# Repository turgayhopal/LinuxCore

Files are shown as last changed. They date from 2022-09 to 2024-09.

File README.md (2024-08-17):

# Linux-Core Development Board

- This project goal is developing myself about embedded linux environment like buildroot, the yacto project.

### Linux Core v2 Features

- NUC980 Series Microprocessor
- 2A Step-Down Voltage Regulator 1.2V, 1.8V, 3.3V
- RLT8188EU WIFI USB Module
- CP2102 USB TTL
- ILI9143 TFT LCD Header
- NAU88C22YG Audio Speaker
- Cam Slot
- SPI Nand External Flash
- MDBT5DQ (NRF52840 Bluetooth Bodule with USB) (Experimental !!!)
- 2 USB Host Socket
- 2 - 2x10 User Pin Header
- SD Card Slot
- 4 User LED's

### PCB Features

- 60.1mm x 80.1mm
- 1mm board thickness.
- 4 layer PCB.
- 0.45 / 0.3 vias

### Linux Core v1 Features

- NUC980 Series Microprocessor
- 2A Step-Down Voltage Regulator 1.2V, 1.8V, 3.3V
- RLT8188EU WIFI USB Module
- CP2102 USB TTL
- 128 KB External SPI-NOR Flash
- SD Card Slot
- 3 User LED's

### PCB Features

- 52.6mm x 57.5mm
- 1.6mm board thickness.
- 2 layer PCB.
- 0.6 / 0.3 vias

## Linux Core v2 Images

### Right Side
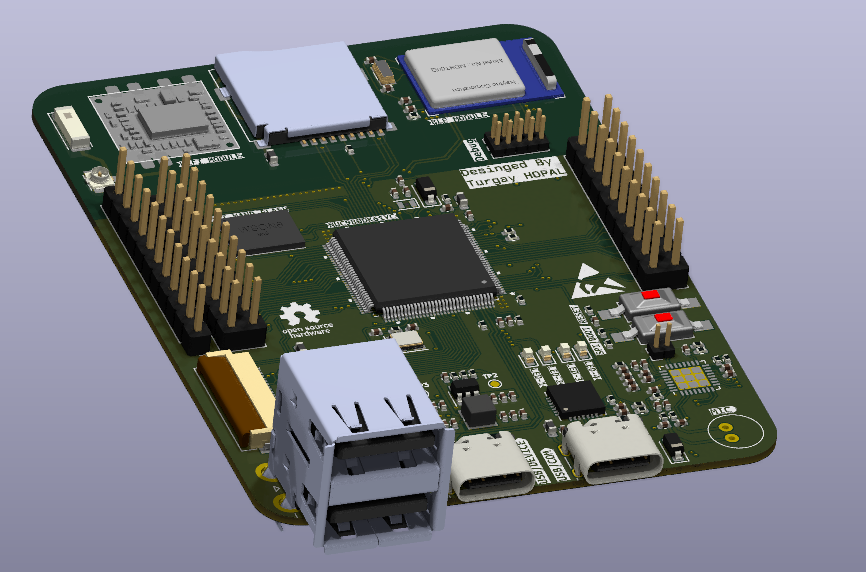
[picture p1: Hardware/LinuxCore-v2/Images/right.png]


### Front Side
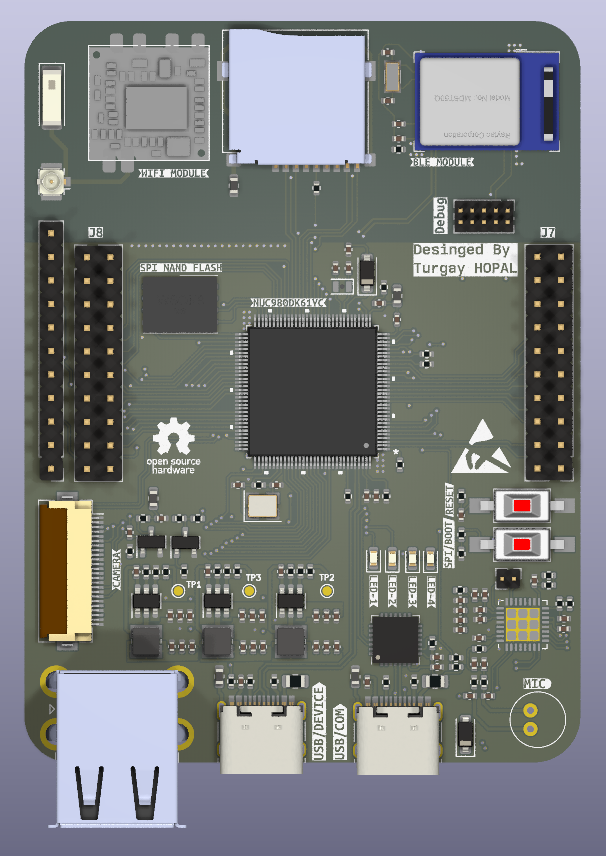
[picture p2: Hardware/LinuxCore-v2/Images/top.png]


### Back Side
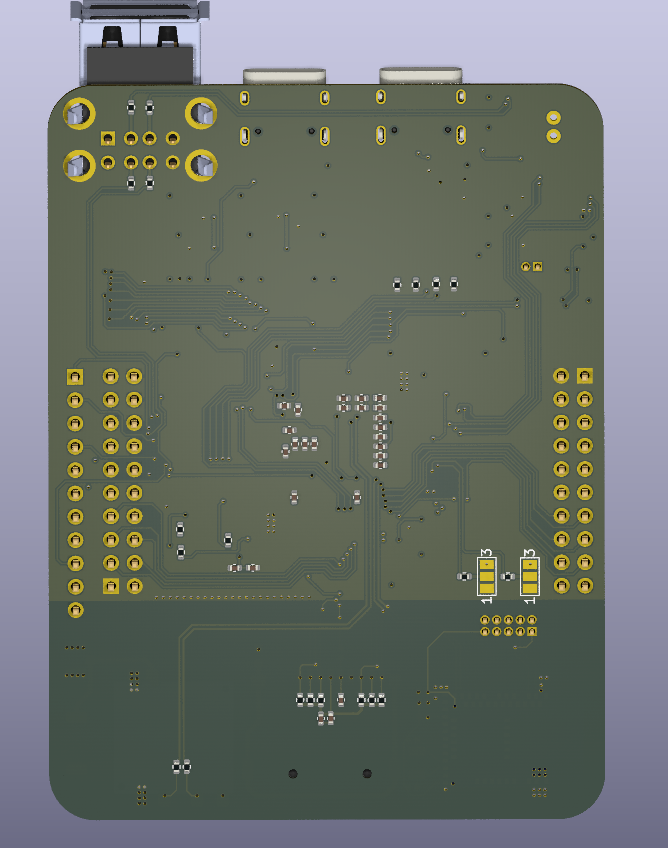
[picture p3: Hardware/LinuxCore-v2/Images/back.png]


### LCD
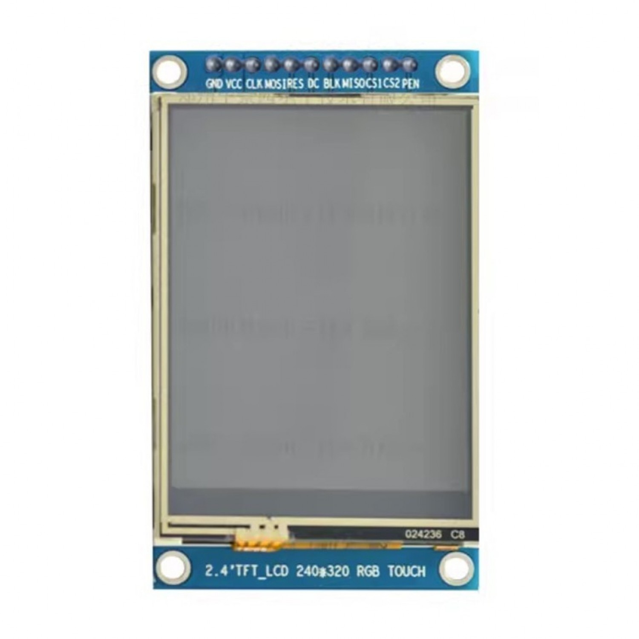
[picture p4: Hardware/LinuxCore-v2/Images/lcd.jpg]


## Linux Core v1 Images

### Right Side
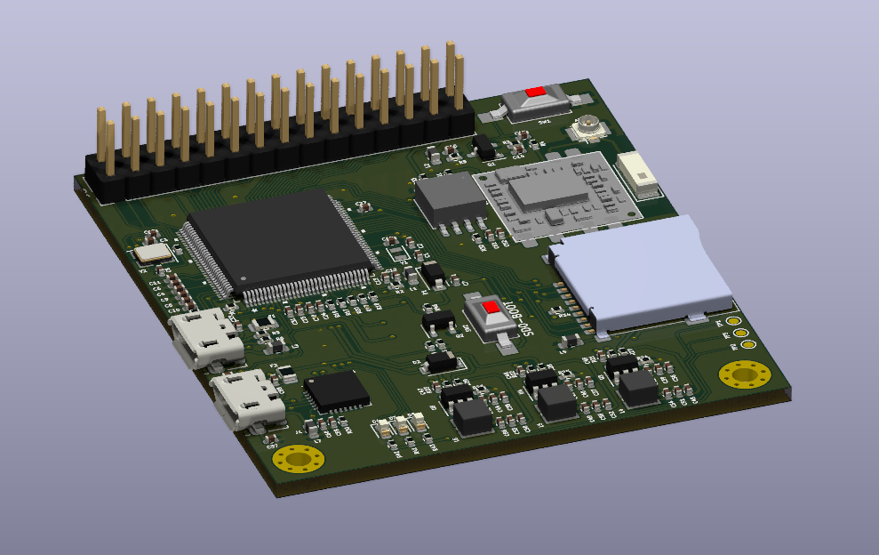
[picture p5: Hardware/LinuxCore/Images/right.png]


### Front Side
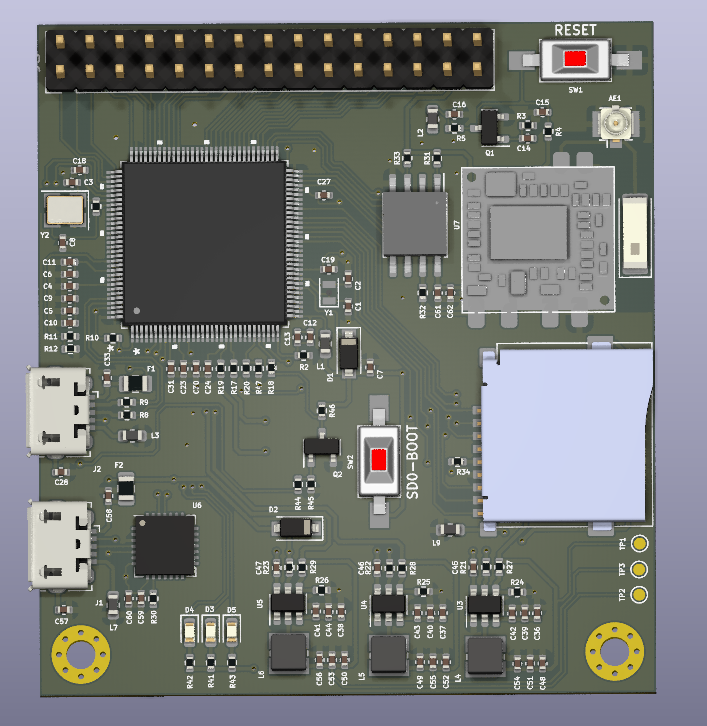
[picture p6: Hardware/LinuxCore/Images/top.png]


### Back Side
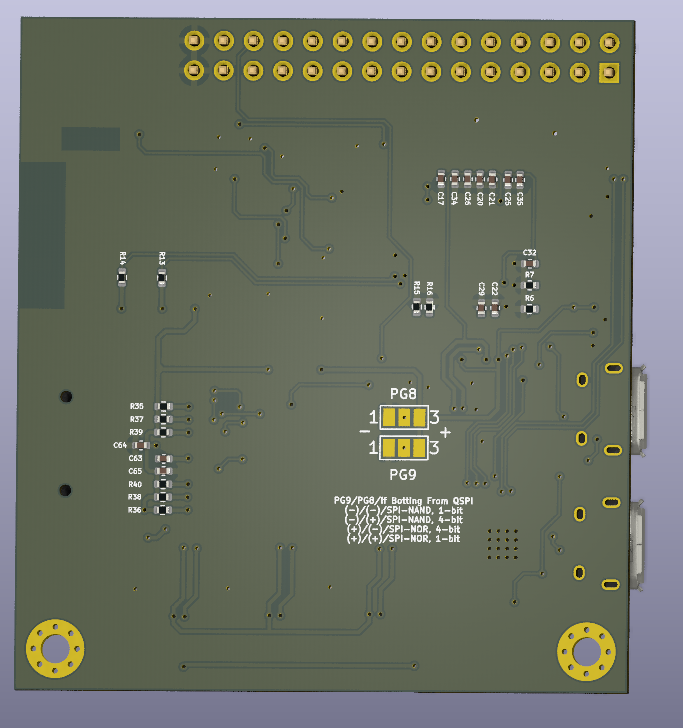
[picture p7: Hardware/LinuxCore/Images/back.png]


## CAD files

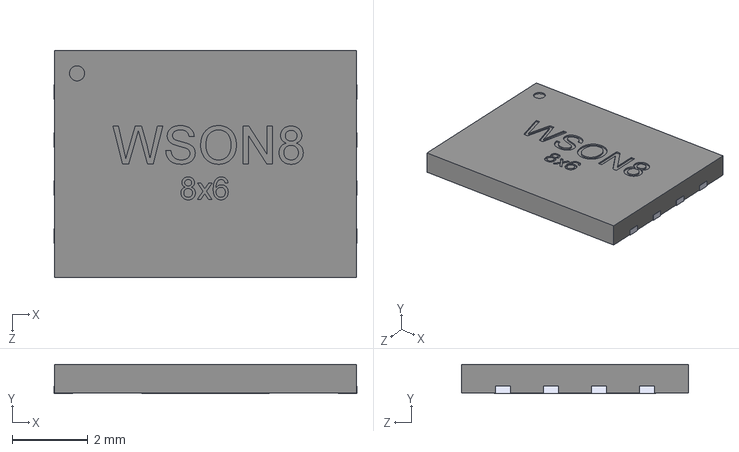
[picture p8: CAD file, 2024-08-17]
Hardware/LinuxCore-v2/3DModels/WSON8-8x6.STEP
8.02 x 0.77 x 6.00 mm

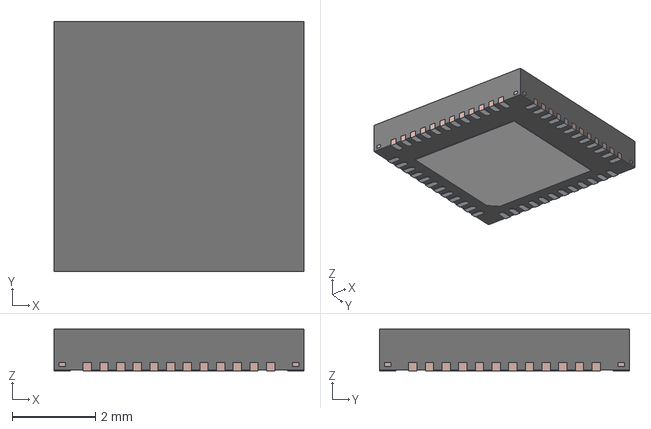
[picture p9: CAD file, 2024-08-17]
Hardware/LinuxCore-v2/3DModels/RSL0048A.stp
6.00 x 6.00 x 1.00 mm
FRAME

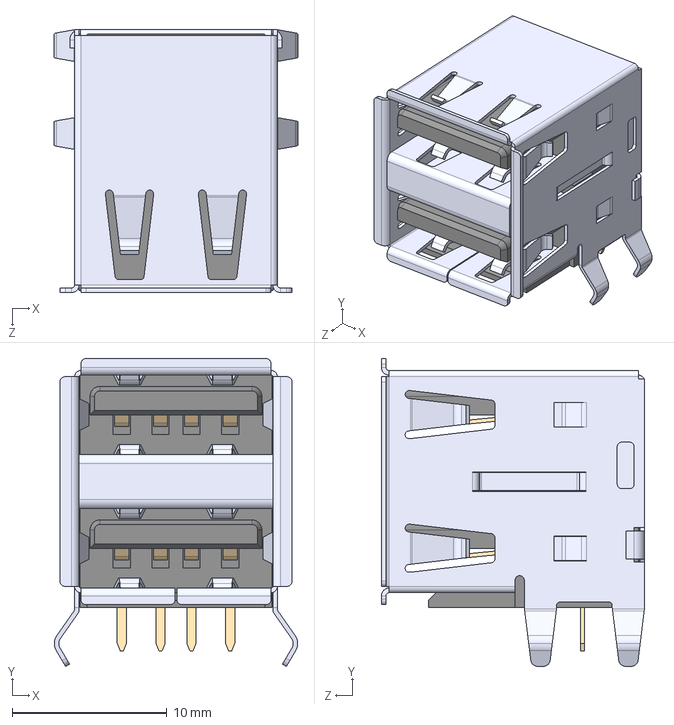
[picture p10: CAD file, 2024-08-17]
Hardware/LinuxCore-v2/3DModels/USB1035-GF-P-0-B-B.STEP
15.7 x 19.9 x 17.0 mm

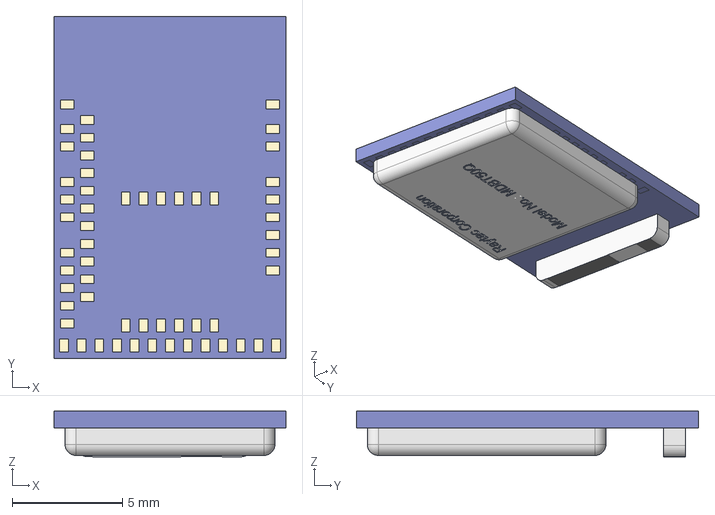
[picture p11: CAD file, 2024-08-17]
Hardware/LinuxCore-v2/3DModels/MDBT50Q-1MV2.STEP
10.5 x 15.5 x 2.06 mm

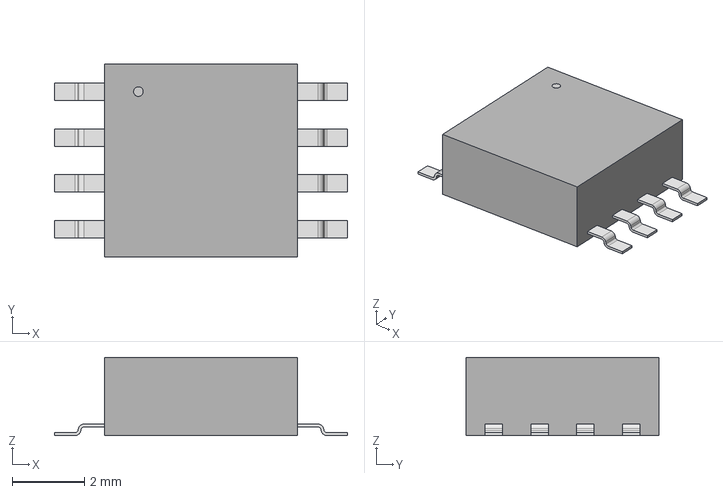
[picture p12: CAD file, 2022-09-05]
Hardware/LinuxCore-v2/3DModels/SOIC_128JVSIM_WIN.step
8.10 x 5.33 x 2.16 mm

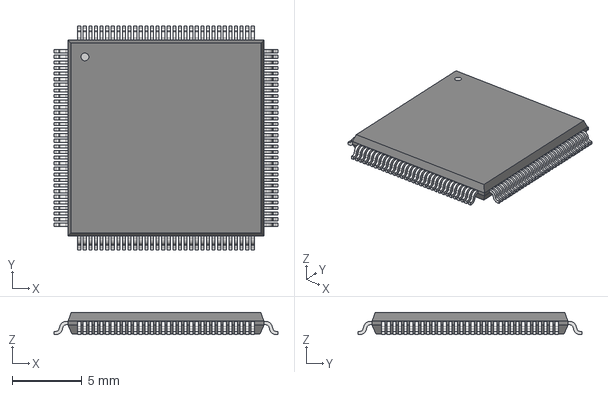
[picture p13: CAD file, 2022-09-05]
Hardware/LinuxCore-v2/3DModels/LQFP128_14X14X1_4_NUV.step
16.0 x 16.0 x 1.60 mm

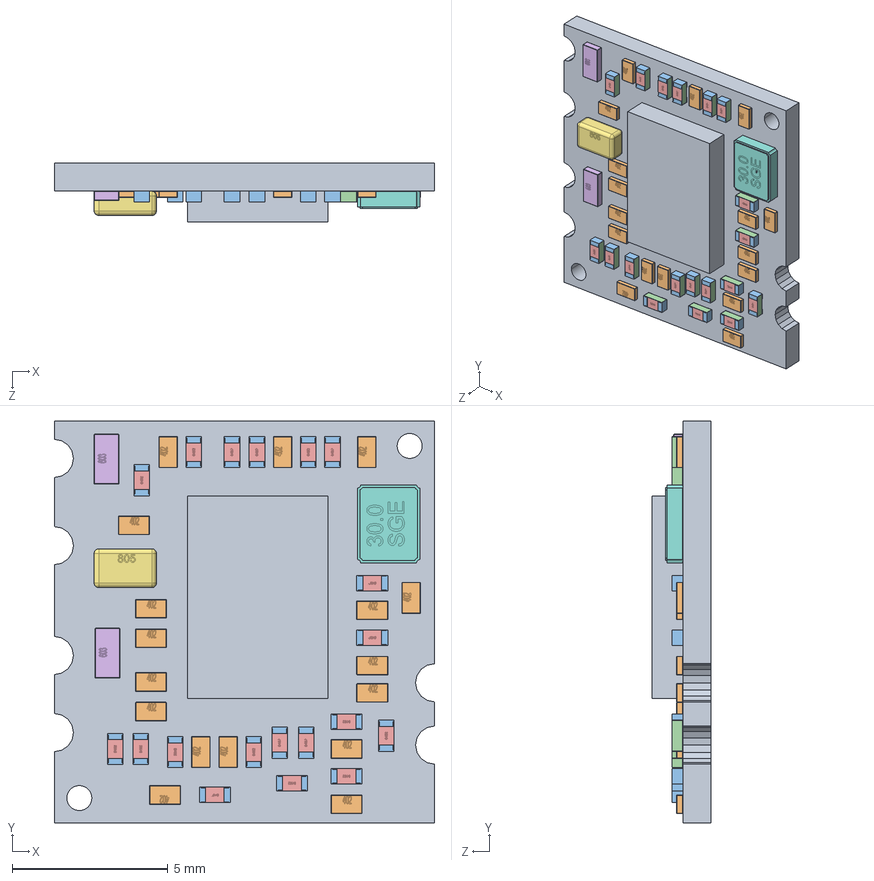
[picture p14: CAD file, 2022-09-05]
Hardware/LinuxCore-v2/3DModels/User Library-JCX12.STEP
12.2 x 12.9 x 1.89 mm
Board
CAP0402 x 17
RES0402 x 19
CAP0603 x 2
CAP0805
SX-2520
Extruded

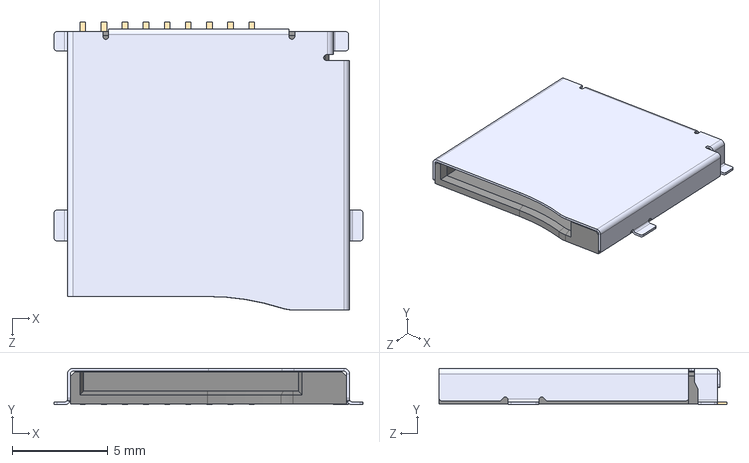
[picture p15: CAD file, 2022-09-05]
Hardware/LinuxCore-v2/3DModels/GTFP08131Y2HR.step
16.1 x 1.90 x 15.0 mm

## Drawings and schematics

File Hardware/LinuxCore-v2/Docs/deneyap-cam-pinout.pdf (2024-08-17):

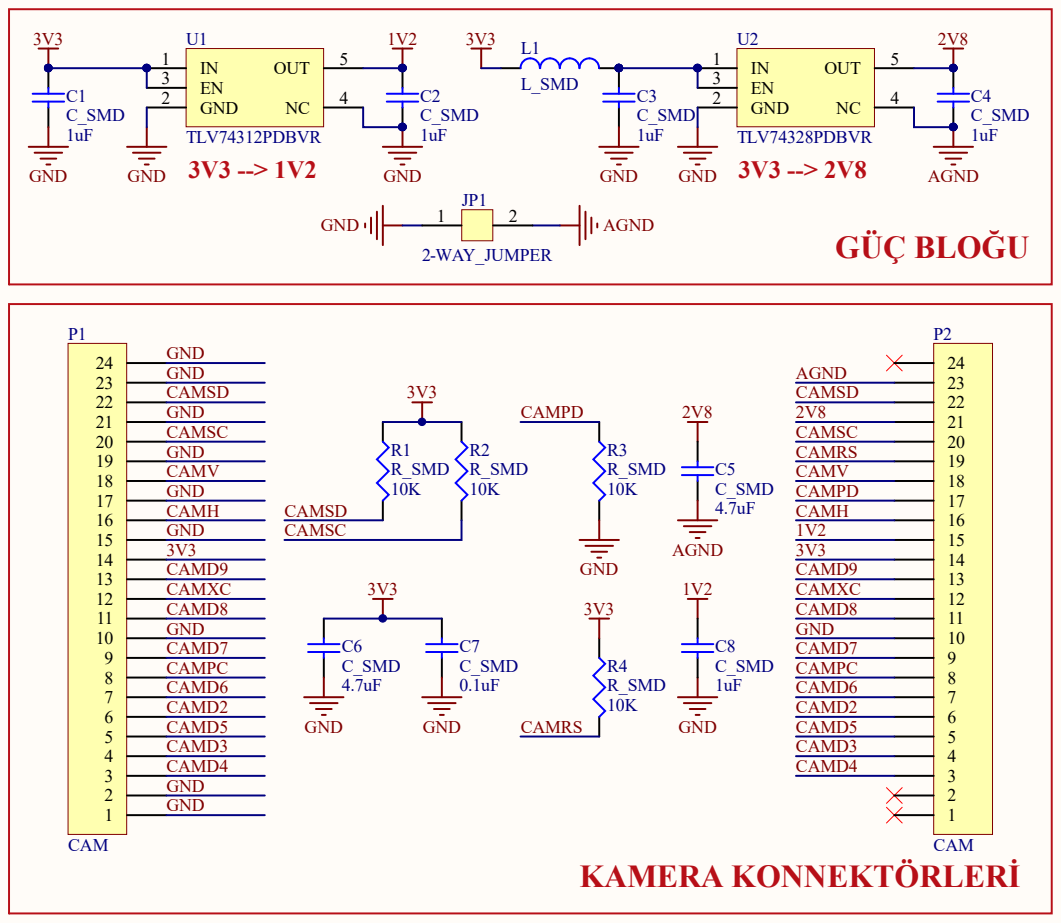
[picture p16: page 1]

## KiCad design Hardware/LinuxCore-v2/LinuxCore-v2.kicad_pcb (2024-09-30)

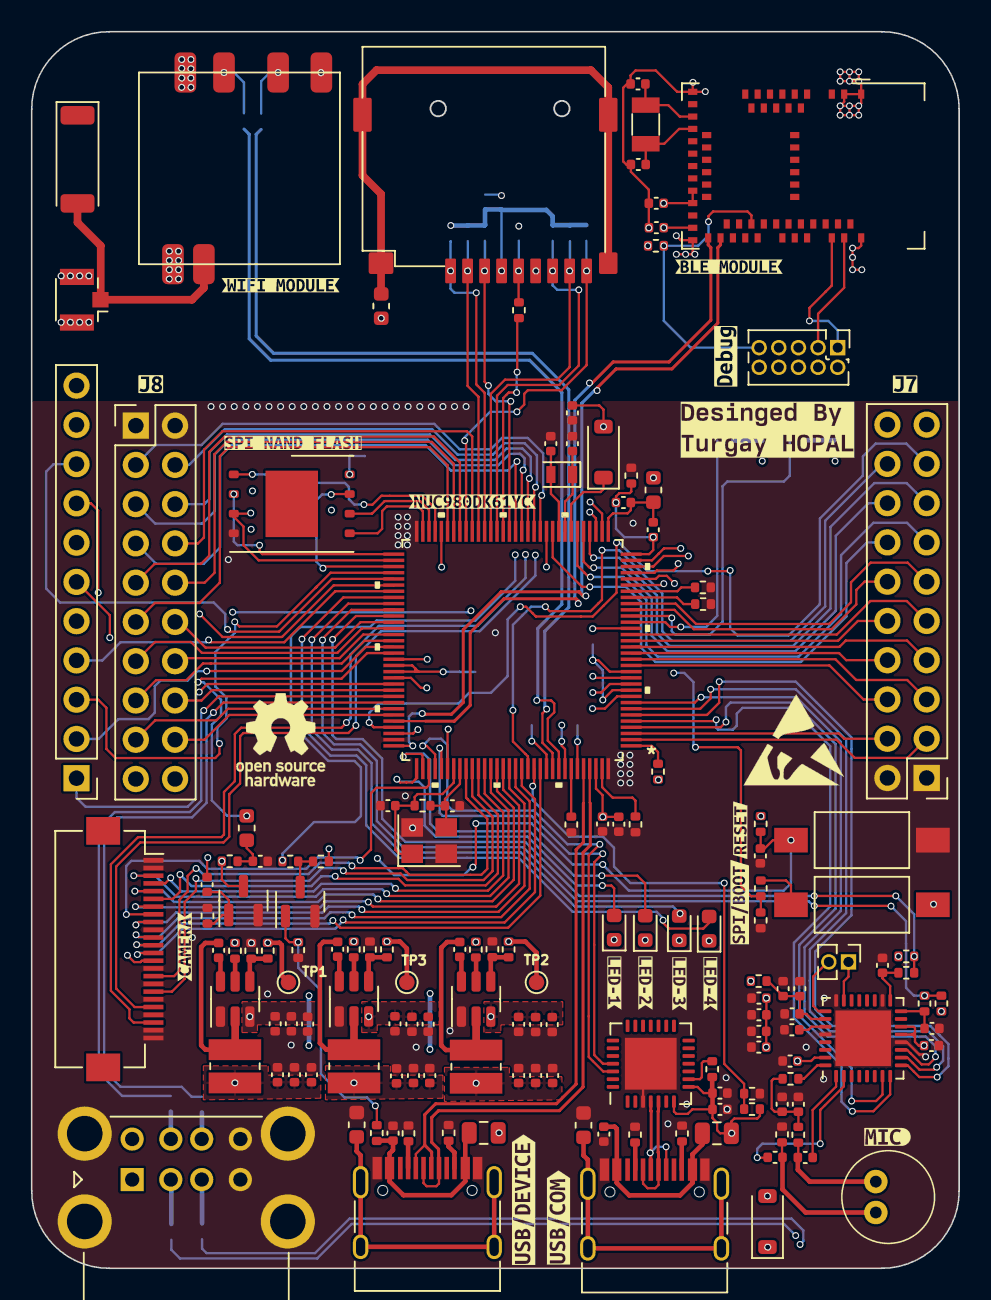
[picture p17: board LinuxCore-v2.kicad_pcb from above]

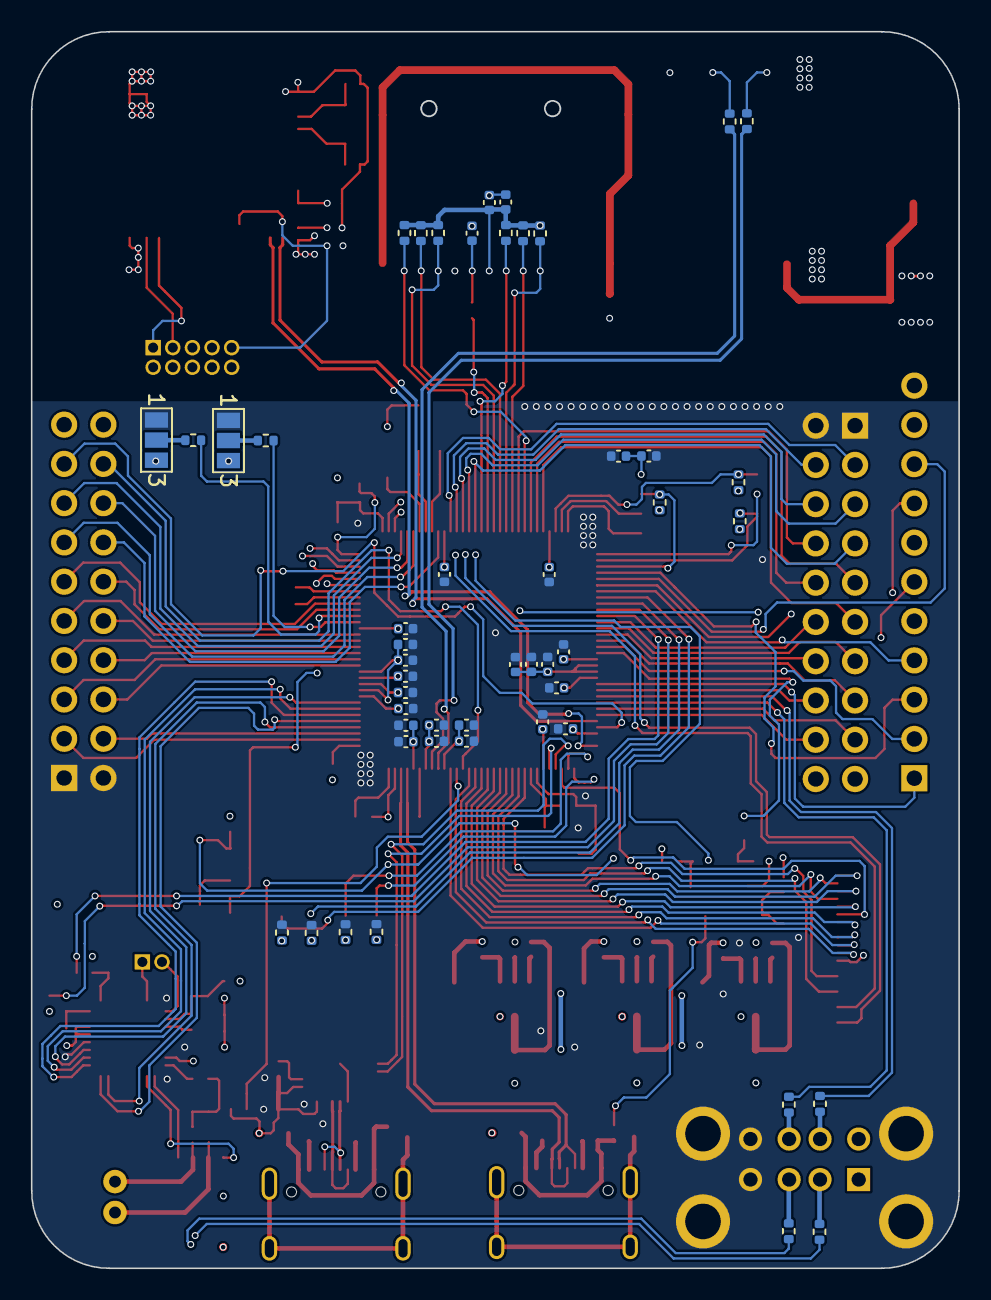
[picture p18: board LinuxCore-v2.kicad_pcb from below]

Board: 4 copper layers, 60.0 x 80.0 mm, 214 parts (49 on the bottom side), 174 nets.

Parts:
AE1: Antenna_Shield; U.FL_Hirose_U.FL-R-SMT-1_Vertical
AE2: Antenna_Shield; Johanson_2450AT43F0100
C1, C2, C3, C8: 15pF; C_0402_1005Metric
C4, C5, C6, C12, C33, C34, C38, C39, C40, C41, C42, C43, C61, C65, C66, C67, C69, C72, C78: 10uF; C_0402_1005Metric
C7, C9, C10, C11, C13, C17, C18, C19, C20, C21, C22, C23, C24, C25, C26, C27, C29, C30, C31, C32, C36, C37, C44, C45, C46, C47, C48, C49, C50, C51, C52, C60: 0.1uF; C_0402_1005Metric
C14, C15, C16, C28, C35, C53, C54, C55, C56, C57, C58, C70, C71: 1uF; C_0402_1005Metric
C59: NC; C_0402_1005Metric
C62, C63, C64, C68, C73, C74, C75, C77, C79: 100nF; C_0402_1005Metric
C76, C82, C83: 4.7uF; C_0402_1005Metric
C80, C81: 12pF; C_0402_1005Metric
D1: 30V 200mA; D_SOD-123
D2: B240; D_SOD-123
D3, D4, D5, D6: LED; LED_0603_1608Metric
F1, F2: 6V/1.5A; Fuse_0805_2012Metric
J1, J2: USB_C_Receptacle_USB2.0; USB_C_Receptacle_HRO_TYPE-C-31-M-12
J3: Conn_01x11_Pin; PinHeader_1x11_P2.54mm_Vertical
J4: Conn_01x24; Hirose_FH12-24S-0.5SH_1x24-1MP_P0.50mm_Horizontal
J5: NRF_Debug; PinHeader_2x05_P1.27mm_Vertical
J6: USB_A_Stacked; USB_A_CUI_UJ2-ADH-TH_Horizontal_Stacked
J7, J8: Conn_02x10_Odd_Even; PinHeader_2x10_P2.54mm_Vertical
JP1, JP2: SolderJumper_3_Open; SolderJumper-3_P1.3mm_Open_Pad1.0x1.5mm_NumberLabels
L1, L2, L3, L4, L8: 220R; L_0603_1608Metric
L5, L6, L7: 2.2uH; L_Wuerth_MAPI-3020
LS1: Speaker; PinHeader_1x02_P1.27mm_Vertical
Q1, Q2: MMBT3904; SOT-23
R1: 1M; R_0402_1005Metric
R2, R37, R48: 0R; R_0402_1005Metric
R3, R4, R12: 100K; R_0402_1005Metric
R5: 470R; R_0402_1005Metric
R6, R21, R23, R60, R61, R62, R63: 1K; R_0402_1005Metric
R7, R8, R25, R26, R56, R57, R58, R59: 5.1K; R_0402_1005Metric
R9: 20K; R_0402_1005Metric
R10: 39K; R_0402_1005Metric
R11, R13: 12.1K; R_0402_1005Metric
R14, R15: 4.7R; R_0402_1005Metric
R16, R17, R18, R19, R20, R22, R24, R27, R28, R29, R30, R31, R32, R33, R38, R39, R40, R41, R42, R43, R52, R53, R54, R55: 10K; R_0402_1005Metric
R34: 33.2K; R_0402_1005Metric
R35: 5.76K; R_0402_1005Metric
R36: 13.7K; R_0402_1005Metric
R44, R45, R46, R47: 33R; R_0402_1005Metric
R49, R50: 2.2K; R_0402_1005Metric
R51: 680R; R_0402_1005Metric
SW1, SW2: SW_Push; SW_SPST_FSMSM
TP1, TP2, TP3: TestPoint; TestPoint_Pad_D1.0mm
U1: NUC980DK61YC
U2: RLT8188_WIFI_MODUL
U3: CP2102N-Axx-xQFN28; QFN-28-1EP_5x5mm_P0.5mm_EP3.35x3.35mm
U4, U5, U6: TPS562200; SOT-23-6
U7: L-KLS1-TF-003; L-KLS1-TF-003-H1.85-R
U8: NAU88C22; QFN-32-1EP_5x5mm_P0.5mm_EP3.6x3.6mm
U9: F35SQA001G
U10: MDBT50Q-P1MV2; Raytac_MDBT50Q
U11: L-KLS3-MM6027PP-443
Y1: Crystal; Crystal_SMD_2012-2Pin_2.0x1.2mm
Y2: Crystal_GND24; Crystal_SMD_3225-4Pin_3.2x2.5mm
Y3: 32.768kHz; Crystal_SMD_3215-2Pin_3.2x1.5mm
kibuzzard-665B7D91: G***; kibuzzard-665B7D91
kibuzzard-665B7DAC: G***; kibuzzard-665B7DAC
kibuzzard-665B7DDA: G***; kibuzzard-665B7DDA
kibuzzard-665B7E6F: G***; kibuzzard-665B7E6F
kibuzzard-665B7E8B: G***; kibuzzard-665B7E8B
kibuzzard-665B7E24: G***; kibuzzard-665B7E24
kibuzzard-665B7E38: G***; kibuzzard-665B7E38
kibuzzard-665B7E84: G***; kibuzzard-665B7E84
kibuzzard-665B7E87: G***; kibuzzard-665B7E87
kibuzzard-665B7EA2: G***; kibuzzard-665B7EA2
kibuzzard-665B7EF0: G***; kibuzzard-665B7EF0
kibuzzard-665B7F01: G***; kibuzzard-665B7F01
kibuzzard-665B7F18: G***; kibuzzard-665B7F18
kibuzzard-665B7F32: G***; kibuzzard-665B7F32
kibuzzard-665B7FB9: G***; kibuzzard-665B7FB9
kibuzzard-665B7FBD: G***; kibuzzard-665B7FBD
kibuzzard-665C90BB: G***; kibuzzard-665C90BB
kibuzzard-665C92C9: G***; kibuzzard-665C92C9

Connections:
+1V2: C6.2, C11.2, C14.1, C17.2, C19.2, C22.2, C25.2, C29.2, C32.2, C34.2, C52.2, C55.2, C58.2, L7.2, R35.2, TP2.1, U1.10 (VDD), U1.13 (VDD), U1.43 (VDD), U1.82 (VDD), U1.94 (VDD), U1.118 (VDD), U1.123 (USB0_VDD)
+1V8: C20.1, C23.1, C26.1, C30.1, C33.1, C51.2, C54.2, C57.2, L6.2, R36.2, TP3.1, U1.11 (MVDD), U1.12 (MVDD), U1.83 (MVDD), U1.84 (MVDD)
+3V3: C4.2, C5.2, C7.2, C9.2, C10.2, C18.1, C21.1, C24.1, C27.1, C31.1, C50.2, C53.2, C56.2, C60.1, C61.1, C62.1, C63.1, C64.1, C66.1, C74.1, C75.2, C78.2, C79.2, C83.2, D1.2 (A), J3.5, J3.7, J3.10, J4.14, J5.2, J7.19, J7.20, J8.19, J8.20, JP1.3 (B), JP2.3 (B), L1.1, L5.2, R4.1, R12.1, R19.1, R34.2, R38.2, R39.2, R40.2, R41.2, R42.2, R43.2, R44.2, R45.2, R48.1, R52.1, R53.2, R54.1, R55.2, SW2.1, TP1.1, U1.9 (VDDIO), U1.20 (VDDIO), U1.60 (VDDIO), U1.85 (VDDIO), U1.102 (VDDIO), U1.121 (USB1_VDD33), U1.126 (USB0_VDD33), U2.1 (3V3), U7.4 (VDD), U8.13 (VDDC), U8.14 (VDDB), U8.31 (VDDA), U9.8 (VCC), U10.28 (VDD), U10.30 (VDDH)
/AUDIO/I2S_BCLK: U1.5 (PA-3), U8.8 (BCLK)
/AUDIO/I2S_DI: U1.6 (PA-4), U8.9 (ADCOUT)
/AUDIO/I2S_DO: U1.7 (PA-5), U8.10 (DACIN)
/AUDIO/I2S_LRCK: U1.4 (PA-2), U8.7 (FS)
/AUDIO/I2S_MCLK: U1.8 (PA-6), U8.11 (MCLK)
/AUDIO/LMICN: C71.2, U8.2 (LMICN)
/AUDIO/LMICP: C70.2, U8.1 (LMICP)
/AUDIO/LSPKOUT: LS1.2, U8.25 (LSPKOUT)
/AUDIO/RSPKOUT: LS1.1, U8.23 (RSPKOUT)
/AUDIO/SCL: R45.1, R47.1, U1.74 (PD-14)
/AUDIO/SCL_: C67.1, R47.2, U8.16 (SCLK)
/AUDIO/SDA: R44.1, R46.1, U1.75 (PD-15)
/AUDIO/SDA_: C65.1, R46.2, U8.17 (SDIO)
/AUDIO/SPK_3V3: C68.1, C69.1, C77.2, R48.2, U8.26 (VDDSPK)
/AUDIO/VREF: C76.2, U8.27 (VREF)
/BLE Module/NRESET: J5.9, R55.1, U10.40 (~RESET/P0.18)
/BLE Module/SWDCLK: J5.3, U10.53 (SWDCLK)
/BLE Module/SWDIO: J5.1, U10.51 (SWDIO)
/BLE Module/USB_D+: U1.96 (PF-7), U10.35 (D+)
/BLE Module/USB_D-: U1.92 (PF-6), U10.34 (D-)
/BLE Module/XL1: C80.1, U10.17 (XL1/P0.00), Y3.1
/BLE Module/XL2: C81.1, U10.18 (XL2/P0.01), Y3.2
/Deneyap Kamera/CAMD2: J4.6, U1.107 (PE-2)
/Deneyap Kamera/CAMD3: J4.4, U1.108 (PE-3)
/Deneyap Kamera/CAMD4: J4.3, U1.109 (PE-4)
/Deneyap Kamera/CAMD5: J4.5, U1.110 (PE-5)
/Deneyap Kamera/CAMD6: J4.7, U1.111 (PE-6)
/Deneyap Kamera/CAMD7: J4.9, U1.112 (PE-7)
/Deneyap Kamera/CAMD8: J4.11, U1.113 (PE-8)
/Deneyap Kamera/CAMD9: J4.13, U1.114 (PE-9)
/Deneyap Kamera/CAMH: J4.16, U1.105 (PE-0)
/Deneyap Kamera/CAMPC: J4.8, U1.99 (PF-10)
/Deneyap Kamera/CAMSC: J4.20, U1.35 (PB-5)
/Deneyap Kamera/CAMSD: J4.22, U1.34 (PB-7)
/Deneyap Kamera/CAMV: J4.18, U1.106 (PE-1)
/Deneyap Kamera/CAMXC: J4.12, U1.117 (PE-12)
/Header1/3: J7.3, U1.2 (PA-0)
/Header1/4: J7.4, U1.3 (PA-1)
/Header1/5: J7.5, U1.15 (PA-8)
/Header1/6: J7.6, U1.14 (PA-7)
/Header1/7: J7.7, U1.17 (PA-10)
/Header1/8: J7.8, U1.16 (PA-9)
/Header1/9: J7.9, U1.19 (PA-12)
/Header1/10: J7.10, U1.18 (PA-11)
/Header1/11: J7.11, U1.24 (PG-6)
/Header1/12: J7.12, U1.23 (PG-7)
/Header1/13: J7.13, U1.38 (PB-2)
/Header1/14: J7.14, U1.42 (PB-8)
/Header1/15: J7.15, U1.36 (PB-1)
/Header1/16: J7.16, U1.37 (PB-3)
/Header1/17: J7.17, U1.93 (PB-13)
/Header1/18: J7.18, U1.115 (PE-10)
/Header2/3: J8.3, U1.44 (PC-0)
/Header2/4: J8.4, U1.45 (PC-1)
/Header2/5: J8.5, U1.47 (PC-3)
/Header2/6: J8.6, U1.46 (PC-2)
/Header2/7: J8.7, U1.48 (PC-4)
/Header2/8: J8.8, U1.55 (PC-11)
/Header2/9: J8.9, U1.57 (PC-13)
/Header2/10: J8.10, U1.58 (PC-14)
/Header2/11: J8.11, U1.59 (PC-15)
/Header2/12: J8.12, U1.76 (PG-11)
/Header2/13: J8.13, U1.77 (PG-12)
/Header2/14: J8.14, U1.78 (PG-13)
/Header2/15: J8.15, U1.79 (PG-14)
/Header2/16: J8.16, U1.87 (PF-1)
/Header2/17: J8.17, U1.90 (PF-4)
/Header2/18: J8.18, U1.91 (PF-5)
/ILI9143 TFT LCD/CLK: J3.9, U1.69 (PD-9)
/ILI9143 TFT LCD/CS1: J3.3, U1.68 (PD-8)
/ILI9143 TFT LCD/CS2: J3.2, U1.80 (PG-15)
/ILI9143 TFT LCD/DC: J3.6, U1.29 (PB-0)
/ILI9143 TFT LCD/MISO: J3.4, U1.71 (PD-11)
/ILI9143 TFT LCD/MOSI: J3.8, U1.70 (PD-10)
/ILI9143 TFT LCD/PEN: J3.1, U1.86 (PF-0)
/MPU/PB4: R56.2, U1.31 (PB-4)
/MPU/PB6: R57.2, U1.30 (PB-6)
/MPU/PC5: R42.1, U1.49 (PC-5), U7.3 (CMD)
/MPU/PC6: R37.2, U1.50 (PC-6)
/MPU/PC7: R43.1, U1.51 (PC-7), U7.7 (DAT0)
/MPU/PC8: R41.1, U1.52 (PC-8), U7.8 (DAT1)
/MPU/PC9: R38.1, U1.53 (PC-9), U7.1 (DAT2)
/MPU/PC10: R40.1, U1.54 (PC-10), U7.2 (CD/DAT3)
/MPU/PC12: R39.1, U1.56 (PC-12), U7.9 (CD)
/MPU/PD2: R53.1, U1.61 (PD-2), U9.1 (CS#)
/MPU/PD3: U1.62 (PD-3), U9.6 (CLK)
/MPU/PD4: U1.63 (PD-4), U9.5 (DI/SIO0)
/MPU/PD5: U1.65 (PD-5), U9.2 (DO/SIO1)
/MPU/PD6: R52.2, U1.66 (PD-6), U9.3 (WP#/SIO2)
/MPU/PD7: R54.2, U1.67 (PD-7), U9.7 (HOLD#/SIO3)
/MPU/PD12: D5.2 (A), U1.72 (PD-12)
/MPU/PD13: D6.2 (A), U1.73 (PD-13)
/MPU/PE11: R9.1, R10.2, U1.116 (PE-11)
/MPU/PF2: R59.2, U1.88 (PF-2)
/MPU/PF3: R58.2, U1.89 (PF-3)
/MPU/PF8: D3.2 (A), U1.97 (PF-8)
/MPU/PF9: D4.2 (A), U1.98 (PF-9)
/MPU/PF11: U1.100 (PF-11), U3.26 (TXD)
/MPU/PF12: U1.101 (PF-12), U3.25 (RXD)
/MPU/PG0: R21.1, U1.28 (PG-0)
/MPU/PG1: R23.1, R24.1, U1.27 (PG-1)
/MPU/PG3: R16.1, U1.26 (PG-3)
/MPU/PG5: R17.1, U1.25 (PG-5)
/MPU/PG8: R20.1, U1.22 (PG-8)
/MPU/PG9: R22.1, U1.21 (PG-9)
/MPU/USB0_D+: J1.A6 (D+), J1.B6 (D+), U1.125 (USB0_DP)
/MPU/USB0_D-: J1.A7 (D-), J1.B7 (D-), U1.124 (USB0_DM)
/MPU/USB0_ID: R12.2, U1.1 (USB0_ID)
/MPU/USB0_REXT: R11.2, U1.127 (USB0_REXT)
/MPU/USB1_D+: R15.2, U1.120 (USB1_DP)
/MPU/USB1_D-: R14.2, U1.119 (USB1_DM)
/MPU/USB1_REXT: R13.2, U1.122 (USB1_REXT)
/MPU/USB_DETECT: Q2.1 (B), R6.1, R18.1
/MPU/X32_IN: C1.1, U1.40 (X32_IN), Y1.1
/MPU/X32_OUT: C2.1, U1.41 (X32_OUT), Y1.2
/MPU/XT_IN: C3.1, R1.1, U1.103 (XT_IN), Y2.1
/MPU/XT_OUT: C8.1, R1.2, U1.104 (XT_OUT), Y2.3
/MPU/nRESET: C15.1, Q1.3 (C), R4.2, R5.2, SW1.2
/MPU/nRST: L2.2, U1.81 (nRESET)
/USB/USB_D+: J2.A6 (D+), J2.B6 (D+), U3.4 (D+)
/USB/USB_D-: J2.A7 (D-), J2.B7 (D-), U3.5 (D-)
/Voltage Supply/SW_1: C49.2, L7.1, U6.2 (SW)
/Voltage Supply/SW_2: C48.2, L6.1, U5.2 (SW)
/Voltage Supply/SW_3: C47.2, L5.1, U4.2 (SW)
/Voltage Supply/VBST_1: C49.1, U6.6 (VBST)
/Voltage Supply/VBST_2: C48.1, U5.6 (VBST)
/Voltage Supply/VBST_3: C47.1, U4.6 (VBST)
/Voltage Supply/VIN: C38.2, C39.2, C40.2, C41.2, C42.2, C43.2, C44.2, C45.2, C46.2, D2.1 (K), R28.2, R29.2, R30.2, U4.3 (VIN), U5.3 (VIN), U6.3 (VIN)
GND: AE1.2 (Shield), C1.2, C2.2, C3.2, C4.1, C5.1, C6.1, C7.1, C8.2, C9.1, C10.1, C11.1, C15.2, C16.1, C17.1, C18.2, C19.1, C20.2, C21.2, C22.1, C23.2, C24.2, C25.1, C26.2, C27.2, C28.1, C29.1, C30.2, C31.2, C32.1, C33.2, C34.1, C35.1, C36.1, C37.2, C38.1, C39.1, C40.1, C41.1, C42.1, C43.1, C44.1, C45.1, C46.1, C50.1, C51.1, C52.1, C53.1, C54.1, C55.1, C56.1, C57.1, C58.1, C59.2, C60.2, C61.2, C62.2, C63.2, C64.2, C65.2, C66.2, C67.2, C68.2, C69.2, C72.2, C73.2, C74.2, C75.1, C76.1, C77.1, C78.1, C79.1, C80.2, C81.2, C82.1, C83.1, J1.A1 (GND), J1.A12 (GND), J1.B1 (GND), J1.B12 (GND), J2.A1 (GND), J2.A12 (GND), J2.B1 (GND), J2.B12 (GND), J3.11, J4.1, J4.2, J4.10, J4.15, J4.17, J4.19, J4.21, J4.23, J4.24, J5.4, J5.6, J6.4 (GND1), J6.8 (GND2), J6.9 (Shield), J7.1, J7.2, J8.1, J8.2, JP1.1 (A), JP2.1 (A), L3.2, L4.2, L8.2, Q1.2 (E), Q2.2 (E), R2.1, R3.2, R7.2, R8.2, R10.1, R11.1, R13.1, R16.2, R17.2, R18.2, R24.2, R25.2, R26.2, R31.1, R32.1, R33.1, R50.2, R60.2, R61.2, R62.2, R63.2, SW1.1, U1.64 (VSS), U1.95 (PLL_VSS), U1.128 (VSS), U2.4 (VSS), U2.5 (VSS), U3.3 (GND), U3.29 (GND), U4.1 (GND), U5.1 (GND), U6.1 (GND), U7.6 (VSS), U8.12 (VSSD), U8.18 (MODE), U8.24 (VSSSPK), U8.28 (VSSA), U8.33 (EPAD), U9.4 (GND), U10.1 (GND), U10.2 (GND), U10.15 (GND), U10.33 (GND), U10.55 (GND), Y2.2, Y2.4
unnamed: AE1.1 (A), AE2.2 (Shield), U2.6 (ANT)
unnamed: C16.2, L2.1, R5.1
unnamed: C28.2, F1.1, J1.A4 (VBUS), J1.A9 (VBUS), J1.B4 (VBUS), J1.B9 (VBUS), R6.2
unnamed: C35.2, F2.1, J2.A4 (VBUS), J2.A9 (VBUS), J2.B4 (VBUS), J2.B9 (VBUS)
unnamed: C70.1, R49.2, U11.1
unnamed: C71.1, R50.1, U11.2
unnamed: C72.1, C73.1, R49.1, R51.2
unnamed: D1.1 (K), U1.39 (VBAT33)
unnamed: D3.1 (K), R61.1
unnamed: D4.1 (K), R62.1
unnamed: D5.1 (K), R63.1
unnamed: D6.1 (K), R60.1
unnamed: J1.A5 (CC1), R7.1
unnamed: J1.B5 (CC2), R8.1
unnamed: J1.S1 (SHIELD), L3.1
unnamed: J2.A5 (CC1), R25.1
unnamed: J2.B5 (CC2), R26.1
unnamed: J2.S1 (SHIELD), L4.1
unnamed: J6.3 (D1+), R56.1
unnamed: J6.2 (D1-), R57.1
unnamed: J6.7 (D2+), R58.1
unnamed: J6.6 (D2-), R59.1
unnamed: JP1.2 (C), R20.2
unnamed: JP2.2 (C), R22.2
unnamed: L8.1, U7.10 (SHIELD), U7.11 (SHIELD), U7.12 (SHIELD), U7.13 (SHIELD)
unnamed: C14.2, Q1.1 (B), R3.1
unnamed: Q2.3 (C), R19.2, R21.2
unnamed: R23.2, SW2.2
unnamed: C12.1, C13.1, L1.2, U1.33 (AVDDADC)
unnamed: C12.2, C13.2, R2.2, U1.32 (AVSSADC)
unnamed: R14.1, U2.2 (USB_DM)
unnamed: R15.1, U2.3 (USB_DP)
unnamed: R27.2, U3.9 (~RST)
unnamed: R28.1, U4.5 (EN)
unnamed: R31.2, R34.1, U4.4 (VFB)
unnamed: R29.1, U5.5 (EN)
unnamed: R32.2, R36.1, U5.4 (VFB)
unnamed: R30.1, U6.5 (EN)
unnamed: R33.2, R35.1, U6.4 (VFB)
unnamed: C59.1, R37.1, U7.5 (CLK)
unnamed: R51.1, U8.32 (MICBIAS)
VBUS: C36.2, C37.1, C82.2, D2.2 (A), F1.2, F2.2, J6.1 (VBUS1), J6.5 (VBUS2), R9.2, R27.1, U3.7 (VREGIN), U3.8 (VBUS), U10.32 (VBUS)

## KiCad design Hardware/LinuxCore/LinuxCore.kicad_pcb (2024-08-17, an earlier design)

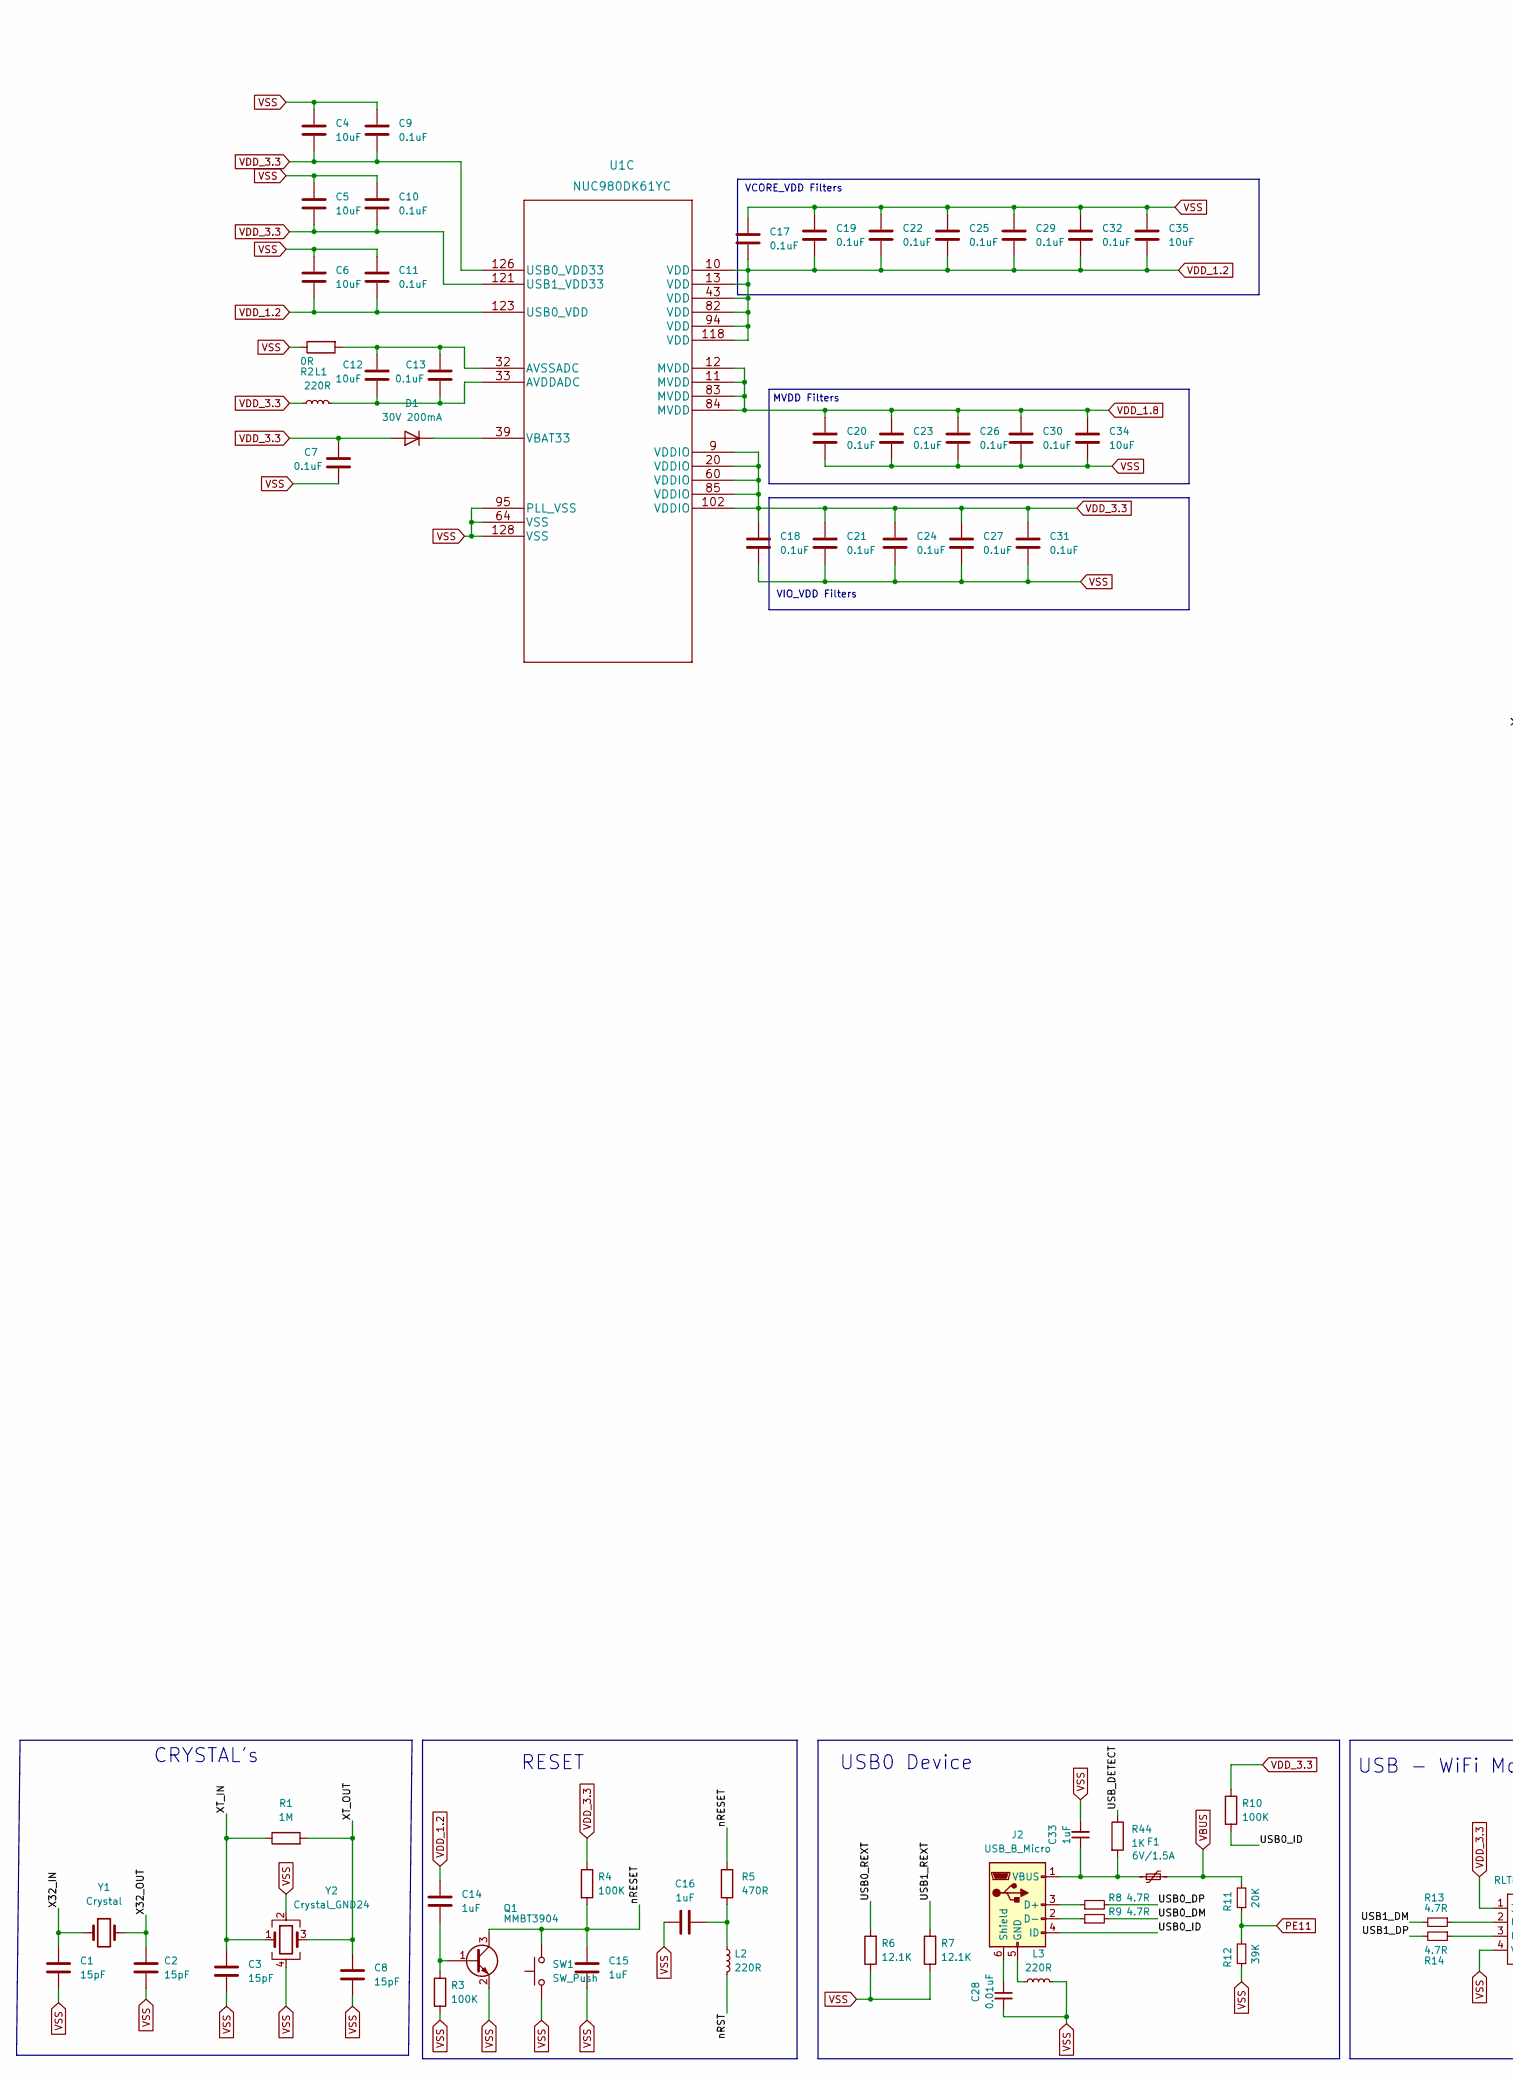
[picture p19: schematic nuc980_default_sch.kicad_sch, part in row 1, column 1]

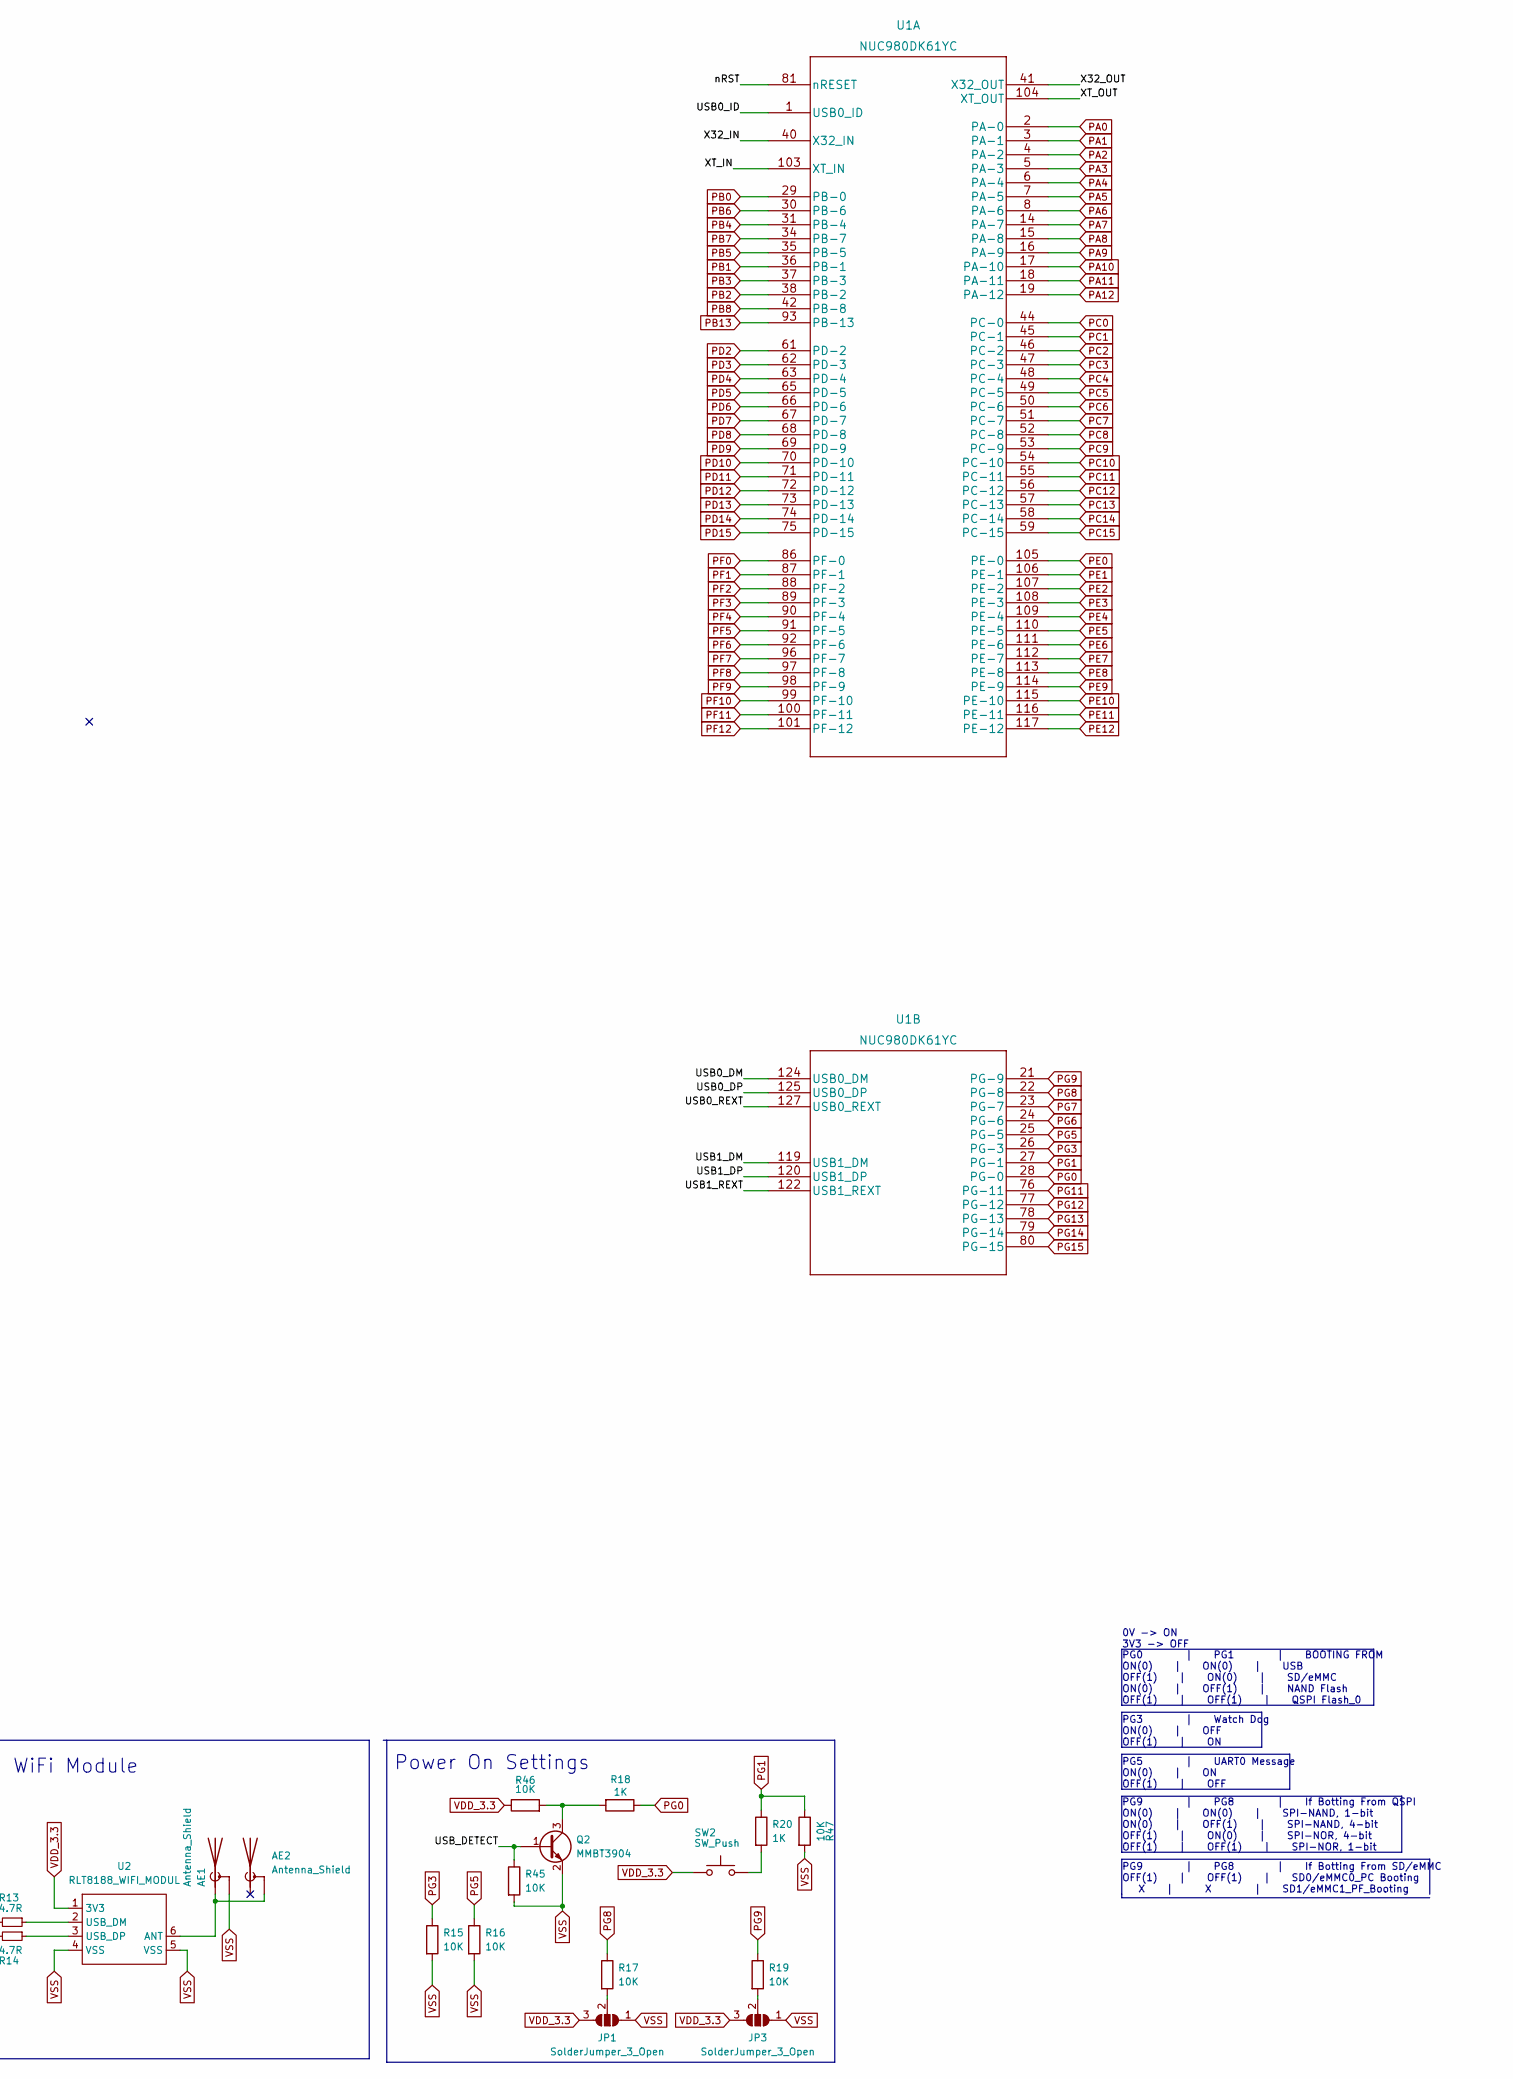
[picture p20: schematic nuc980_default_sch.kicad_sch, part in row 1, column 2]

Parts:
AE1: Antenna_Shield; U.FL_Hirose_U.FL-R-SMT-1_Vertical
AE2: Antenna_Shield; Johanson_2450AT43F0100
C1, C2, C3, C8: 15pF; C_0402_1005Metric
C4, C5, C6, C12, C34, C35: 10uF; C_0402_1005Metric
C7, C9, C10, C11, C13, C17, C18, C19, C20, C21, C22, C23, C24, C25, C26, C27, C29, C30, C31, C32: 0.1uF; C_0402_1005Metric
C14, C15, C16, C33: 1uF; C_0402_1005Metric
C28: 0.01uF; C_0402_1005Metric
D1: 30V 200mA; D_SOD-123
F1: 6V/1.5A; Fuse_0805_2012Metric
J2: USB_B_Micro; USB_Micro-B_Amphenol_10118194_Horizontal
JP1, JP3: SolderJumper_3_Open; SolderJumper-3_P1.3mm_Open_Pad1.0x1.5mm_NumberLabels
L1, L2, L3: 220R; L_0603_1608Metric
Q1, Q2: MMBT3904; SOT-23
R1: 1M; R_0402_1005Metric
R2: 0R; R_0402_1005Metric
R3, R4, R10: 100K; R_0402_1005Metric
R5: 470R; R_0402_1005Metric
R6, R7: 12.1K; R_0402_1005Metric
R8, R9, R13, R14: 4.7R; R_0402_1005Metric
R11: 20K; R_0402_1005Metric
R12: 39K; R_0402_1005Metric
R15, R16, R17, R19, R45, R46, R47: 10K; R_0402_1005Metric
R18, R20, R44: 1K; R_0402_1005Metric
SW1, SW2: SW_Push; SW_SPST_FSMSM
U1: NUC980DK61YC
U2: RLT8188_WIFI_MODUL
Y1: Crystal; Crystal_SMD_2012-2Pin_2.0x1.2mm
Y2: Crystal_GND24; Crystal_SMD_3225-4Pin_3.2x2.5mm

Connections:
/NUC980/USB0_DM: R9.2, U1.124 (USB0_DM)
/NUC980/USB0_DP: R8.2, U1.125 (USB0_DP)
/NUC980/USB0_ID: J2.4 (ID), R10.2, U1.1 (USB0_ID)
/NUC980/USB0_REXT: R6.2, U1.127 (USB0_REXT)
/NUC980/USB1_DM: R13.2, U1.119 (USB1_DM)
/NUC980/USB1_DP: R14.2, U1.120 (USB1_DP)
/NUC980/USB1_REXT: R7.2, U1.122 (USB1_REXT)
/NUC980/USB_DETECT: Q2.1 (B), R44.1, R45.1
/NUC980/X32_IN: C1.1, U1.40 (X32_IN), Y1.1
/NUC980/X32_OUT: C2.1, U1.41 (X32_OUT), Y1.2
/NUC980/XT_IN: C3.1, R1.1, U1.103 (XT_IN), Y2.1
/NUC980/XT_OUT: C8.1, R1.2, U1.104 (XT_OUT), Y2.3
/NUC980/nRESET: C15.1, Q1.3 (C), R4.2, R5.2, SW1.2
/NUC980/nRST: L2.2, U1.81 (nRESET)
unnamed: AE1.1 (A), AE2.2 (Shield), U2.6 (ANT)
unnamed: C12.1, C13.1, L1.2, U1.33 (AVDDADC)
unnamed: C12.2, C13.2, R2.2, U1.32 (AVSSADC)
unnamed: C14.2, Q1.1 (B), R3.1
unnamed: C16.2, L2.1, R5.1
unnamed: C28.1, J2.6 (Shield)
unnamed: C33.1, F1.1, J2.1 (VBUS), R44.2
unnamed: D1.1 (K), U1.39 (VBAT33)
unnamed: J2.2 (D-), R9.1
unnamed: J2.3 (D+), R8.1
unnamed: J2.5 (GND), L3.1
unnamed: JP1.2 (C), R17.2
unnamed: JP3.2 (C), R19.2
unnamed: R13.1, U2.2 (USB_DM)
unnamed: R14.1, U2.3 (USB_DP)
unnamed: Q2.3 (C), R18.2, R46.2
unnamed: R20.2, SW2.2
PA0: U1.2 (PA-0)
PA1: U1.3 (PA-1)
PA2: U1.4 (PA-2)
PA3: U1.5 (PA-3)
PA4: U1.6 (PA-4); also elsewhere on the board
PA5: U1.7 (PA-5); also elsewhere on the board
PA6: U1.8 (PA-6); also elsewhere on the board
PA7: U1.14 (PA-7)
PA8: U1.15 (PA-8)
PA9: U1.16 (PA-9)
PA10: U1.17 (PA-10)
PA11: U1.18 (PA-11)
PA12: U1.19 (PA-12)
PB0: U1.29 (PB-0); also elsewhere on the board
PB1: U1.36 (PB-1)
PB2: U1.38 (PB-2)
PB3: U1.37 (PB-3)
PB4: U1.31 (PB-4)
PB5: U1.35 (PB-5)
PB6: U1.30 (PB-6)
PB7: U1.34 (PB-7)
PB8: U1.42 (PB-8)
PB13: U1.93 (PB-13); also elsewhere on the board
PC0: U1.44 (PC-0)
PC1: U1.45 (PC-1)
PC2: U1.46 (PC-2)
PC3: U1.47 (PC-3)
PC4: U1.48 (PC-4)
PC5: U1.49 (PC-5); also elsewhere on the board
PC6: U1.50 (PC-6); also elsewhere on the board
PC7: U1.51 (PC-7); also elsewhere on the board
PC8: U1.52 (PC-8); also elsewhere on the board
PC9: U1.53 (PC-9); also elsewhere on the board
PC10: U1.54 (PC-10); also elsewhere on the board
PC11: U1.55 (PC-11)
PC12: U1.56 (PC-12); also elsewhere on the board
PC13: U1.57 (PC-13)
PC14: U1.58 (PC-14)
PC15: U1.59 (PC-15)
PD2: U1.61 (PD-2); also elsewhere on the board
PD3: U1.62 (PD-3); also elsewhere on the board
PD4: U1.63 (PD-4); also elsewhere on the board
PD5: U1.65 (PD-5); also elsewhere on the board
PD6: U1.66 (PD-6); also elsewhere on the board
PD7: U1.67 (PD-7); also elsewhere on the board
PD8: U1.68 (PD-8); also elsewhere on the board
PD9: U1.69 (PD-9); also elsewhere on the board
PD10: U1.70 (PD-10); also elsewhere on the board
PD11: U1.71 (PD-11); also elsewhere on the board
PD12: U1.72 (PD-12); also elsewhere on the board
PD13: U1.73 (PD-13); also elsewhere on the board
PD14: U1.74 (PD-14); also elsewhere on the board
PD15: U1.75 (PD-15); also elsewhere on the board
PE0: U1.105 (PE-0)
PE1: U1.106 (PE-1)
PE2: U1.107 (PE-2)
PE3: U1.108 (PE-3)
PE4: U1.109 (PE-4)
PE5: U1.110 (PE-5)
PE6: U1.111 (PE-6)
PE7: U1.112 (PE-7)
PE8: U1.113 (PE-8)
PE9: U1.114 (PE-9)
PE10: U1.115 (PE-10)
PE11: R11.1, R12.2, U1.116 (PE-11)
PE12: U1.117 (PE-12)
PF0: U1.86 (PF-0); also elsewhere on the board
PF1: U1.87 (PF-1); also elsewhere on the board
PF2: U1.88 (PF-2); also elsewhere on the board
PF3: U1.89 (PF-3); also elsewhere on the board
PF4: U1.90 (PF-4); also elsewhere on the board
PF5: U1.91 (PF-5); also elsewhere on the board
PF6: U1.92 (PF-6); also elsewhere on the board
PF7: U1.96 (PF-7); also elsewhere on the board
PF8: U1.97 (PF-8); also elsewhere on the board
PF9: U1.98 (PF-9); also elsewhere on the board
PF10: U1.99 (PF-10); also elsewhere on the board
PF11: U1.100 (PF-11); also elsewhere on the board
PF12: U1.101 (PF-12); also elsewhere on the board
PG0: R18.1, U1.28 (PG-0)
PG1: R20.1, R47.1, U1.27 (PG-1)
PG3: R15.1, U1.26 (PG-3)
PG5: R16.1, U1.25 (PG-5)
PG6: U1.24 (PG-6)
PG7: U1.23 (PG-7)
PG8: R17.1, U1.22 (PG-8)
PG9: R19.1, U1.21 (PG-9)
PG11: U1.76 (PG-11); also elsewhere on the board
PG12: U1.77 (PG-12); also elsewhere on the board
PG13: U1.78 (PG-13); also elsewhere on the board
PG14: U1.79 (PG-14); also elsewhere on the board
PG15: U1.80 (PG-15); also elsewhere on the board
VBUS: F1.2, R11.2; also elsewhere on the board
VDD_1.2: C6.2, C11.2, C14.1, C17.2, C19.2, C22.2, C25.2, C29.2, C32.2, C35.2, U1.10 (VDD), U1.13 (VDD), U1.43 (VDD), U1.82 (VDD), U1.94 (VDD), U1.118 (VDD), U1.123 (USB0_VDD); also elsewhere on the board
VDD_1.8: C20.1, C23.1, C26.1, C30.1, C34.1, U1.11 (MVDD), U1.12 (MVDD), U1.83 (MVDD), U1.84 (MVDD); also elsewhere on the board
VDD_3.3: C4.2, C5.2, C7.2, C9.2, C10.2, C18.1, C21.1, C24.1, C27.1, C31.1, D1.2 (A), JP1.3 (B), JP3.3 (B), L1.1, R4.1, R10.1, R46.1, SW2.1, U1.9 (VDDIO), U1.20 (VDDIO), U1.60 (VDDIO), U1.85 (VDDIO), U1.102 (VDDIO), U1.121 (USB1_VDD33), U1.126 (USB0_VDD33), U2.1 (3V3); also elsewhere on the board
VSS: AE1.2 (Shield), C1.2, C2.2, C3.2, C4.1, C5.1, C6.1, C7.1, C8.2, C9.1, C10.1, C11.1, C15.2, C16.1, C17.1, C18.2, C19.1, C20.2, C21.2, C22.1, C23.2, C24.2, C25.1, C26.2, C27.2, C28.2, C29.1, C30.2, C31.2, C32.1, C33.2, C34.2, C35.1, JP1.1 (A), JP3.1 (A), L3.2, Q1.2 (E), Q2.2 (E), R2.1, R3.2, R6.1, R7.1, R12.1, R15.2, R16.2, R45.2, R47.2, SW1.1, U1.64 (VSS), U1.95 (PLL_VSS), U1.128 (VSS), U2.4 (VSS), U2.5 (VSS), Y2.2, Y2.4; also elsewhere on the board

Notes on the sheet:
PG9 | PG8 | If Botting From SD/eMMC OFF(1) | OFF(1) | SD0/eMMC0_PC Booting X | X | SD1/eMMC1_PF_Booting
MVDD Filters
RESET
USB0 Device
VCORE_VDD Filters
USB - WiFi Module
PG0 | PG1 | BOOTING FROM ON(0) | ON(0) | USB OFF(1) | ON(0) | SD/eMMC ON(0) | OFF(1) | NAND Flash OFF(1) | OFF(1) | QSPI Flash_0
0V -> ON 3V3 -> OFF
PG9 | PG8 | If Botting From QSPI ON(0) | ON(0) | SPI-NAND, 1-bit ON(0) | OFF(1) | SPI-NAND, 4-bit OFF(1) | ON(0) | SPI-NOR, 4-bit OFF(1) | OFF(1) | SPI-NOR, 1-bit
PG5 | UART0 Message ON(0) | ON OFF(1) | OFF
CRYSTAL's
Power On Settings
VIO_VDD Filters
PG3 | Watch Dog ON(0) | OFF OFF(1) | ON

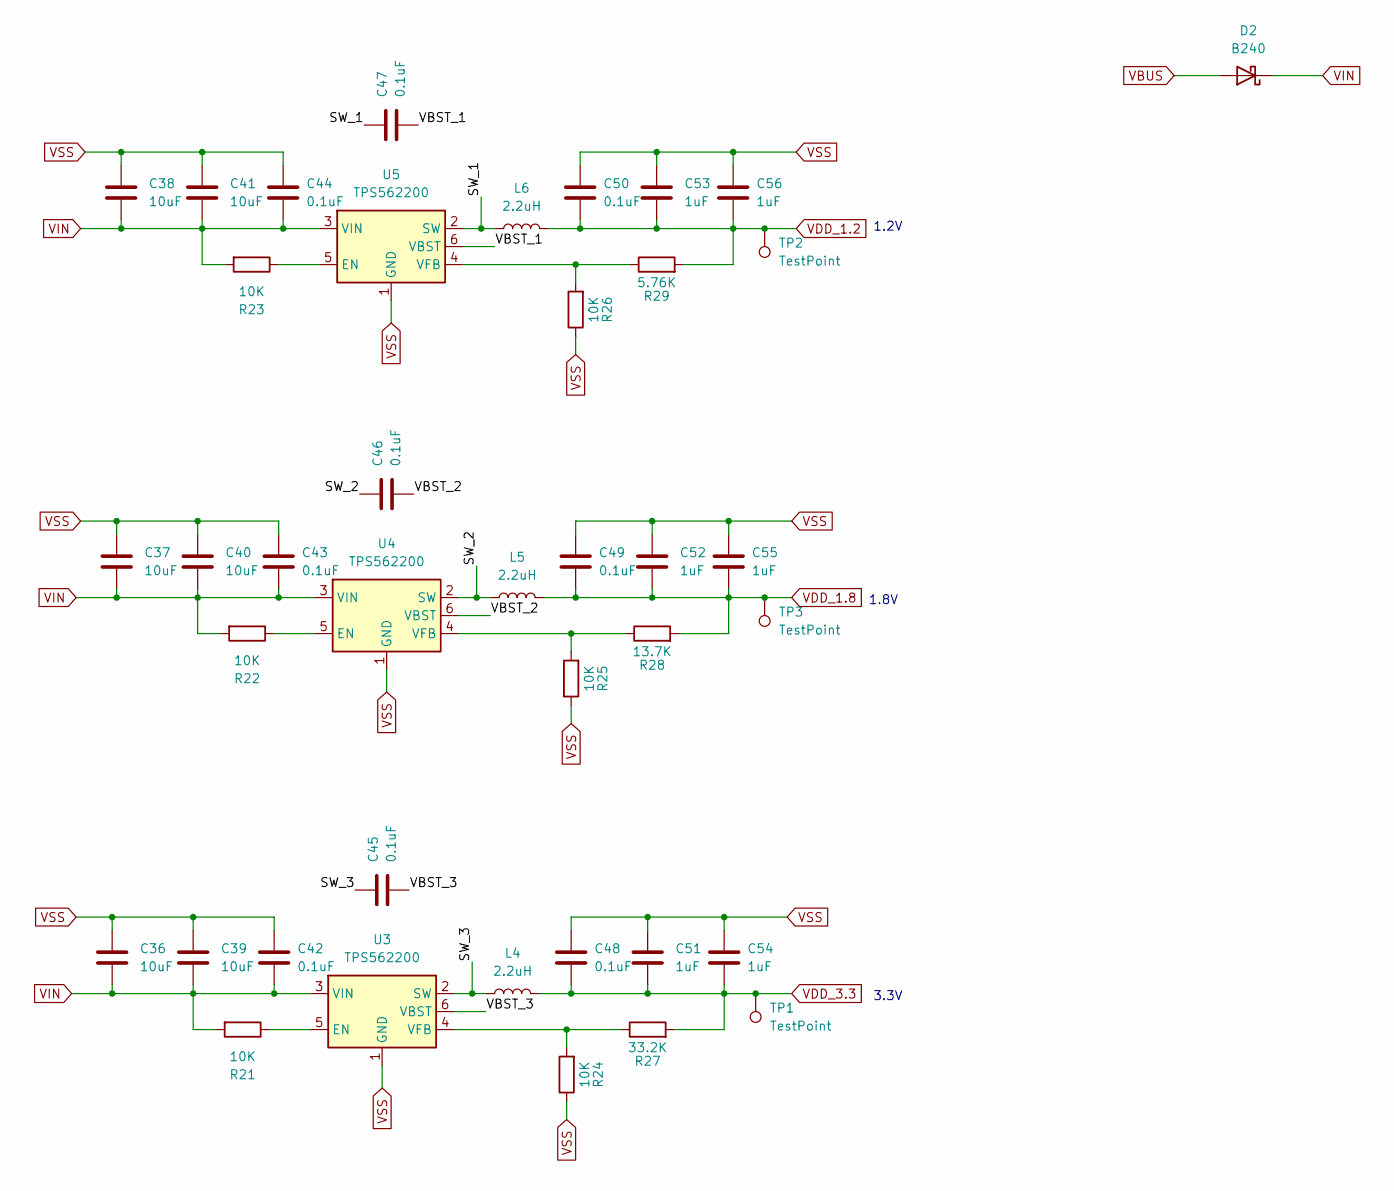
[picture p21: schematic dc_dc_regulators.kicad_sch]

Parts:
C36, C37, C38, C39, C40, C41: 10uF; C_0402_1005Metric
C42, C43, C44, C45, C46, C47, C48, C49, C50: 0.1uF; C_0402_1005Metric
C51, C52, C53, C54, C55, C56: 1uF; C_0402_1005Metric
D2: B240; D_SOD-123
L4, L5, L6: 2.2uH; L_Wuerth_MAPI-3020
R21, R22, R23, R24, R25, R26: 10K; R_0402_1005Metric
R27: 33.2K; R_0402_1005Metric
R28: 13.7K; R_0402_1005Metric
R29: 5.76K; R_0402_1005Metric
TP1, TP2, TP3: TestPoint; TestPoint_Pad_D1.0mm
U3, U4, U5: TPS562200; SOT-23-6

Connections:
/DC-DC Regulators/SW_1: C47.2, L6.1, U5.2 (SW)
/DC-DC Regulators/SW_2: C46.2, L5.1, U4.2 (SW)
/DC-DC Regulators/SW_3: C45.2, L4.1, U3.2 (SW)
/DC-DC Regulators/VBST_1: C47.1, U5.6 (VBST)
/DC-DC Regulators/VBST_2: C46.1, U4.6 (VBST)
/DC-DC Regulators/VBST_3: C45.1, U3.6 (VBST)
unnamed: R21.1, U3.5 (EN)
unnamed: R22.1, U4.5 (EN)
unnamed: R23.1, U5.5 (EN)
unnamed: R24.2, R27.1, U3.4 (VFB)
unnamed: R25.2, R28.1, U4.4 (VFB)
unnamed: R26.2, R29.1, U5.4 (VFB)
VBUS: D2.2 (A); also elsewhere on the board
VDD_1.2: C50.2, C53.2, C56.2, L6.2, R29.2, TP2.1; also elsewhere on the board
VDD_1.8: C49.2, C52.2, C55.2, L5.2, R28.2, TP3.1; also elsewhere on the board
VDD_3.3: C48.2, C51.2, C54.2, L4.2, R27.2, TP1.1; also elsewhere on the board
VIN: C36.2, C37.2, C38.2, C39.2, C40.2, C41.2, C42.2, C43.2, C44.2, D2.1 (K), R21.2, R22.2, R23.2, U3.3 (VIN), U4.3 (VIN), U5.3 (VIN)
VSS: C36.1, C37.1, C38.1, C39.1, C40.1, C41.1, C42.1, C43.1, C44.1, C48.1, C49.1, C50.1, C51.1, C52.1, C53.1, C54.1, C55.1, C56.1, R24.1, R25.1, R26.1, U3.1 (GND), U4.1 (GND), U5.1 (GND); also elsewhere on the board

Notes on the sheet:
1.2V
3.3V
1.8V

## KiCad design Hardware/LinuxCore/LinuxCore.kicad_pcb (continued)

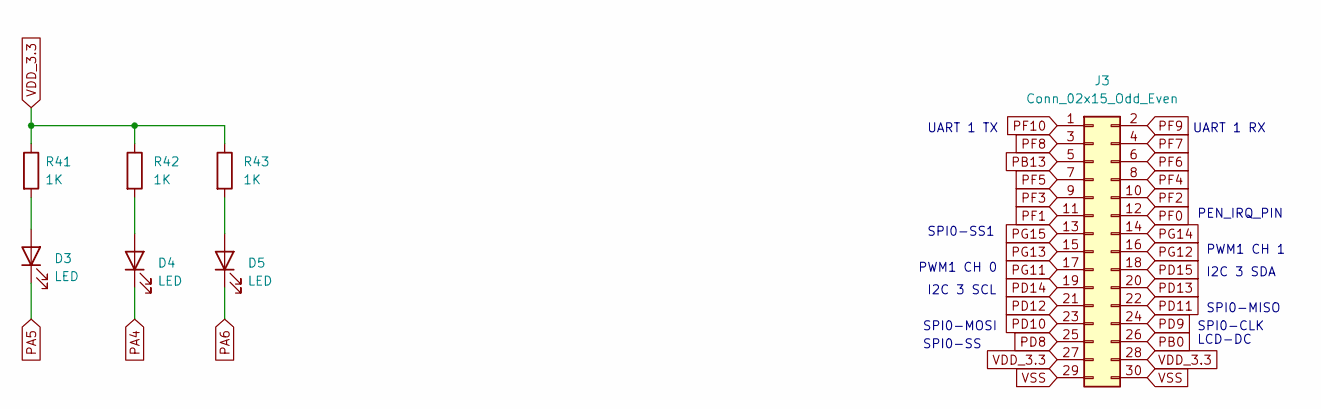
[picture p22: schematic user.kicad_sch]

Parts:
D3, D4, D5: LED; LED_0603_1608Metric
J3: Conn_02x15_Odd_Even; PinHeader_2x15_P2.54mm_Vertical
R41, R42, R43: 1K; R_0402_1005Metric

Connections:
unnamed: D3.2 (A), R41.2
unnamed: D4.2 (A), R42.2
unnamed: D5.2 (A), R43.2
PA4: D4.1 (K); also elsewhere on the board
PA5: D3.1 (K); also elsewhere on the board
PA6: D5.1 (K); also elsewhere on the board
PB0: J3.26; also elsewhere on the board
PB13: J3.5; also elsewhere on the board
PD8: J3.25; also elsewhere on the board
PD9: J3.24; also elsewhere on the board
PD10: J3.23; also elsewhere on the board
PD11: J3.22; also elsewhere on the board
PD12: J3.21; also elsewhere on the board
PD13: J3.20; also elsewhere on the board
PD14: J3.19; also elsewhere on the board
PD15: J3.18; also elsewhere on the board
PF0: J3.12; also elsewhere on the board
PF1: J3.11; also elsewhere on the board
PF2: J3.10; also elsewhere on the board
PF3: J3.9; also elsewhere on the board
PF4: J3.8; also elsewhere on the board
PF5: J3.7; also elsewhere on the board
PF6: J3.6; also elsewhere on the board
PF7: J3.4; also elsewhere on the board
PF8: J3.3; also elsewhere on the board
PF9: J3.2; also elsewhere on the board
PF10: J3.1; also elsewhere on the board
PG11: J3.17; also elsewhere on the board
PG12: J3.16; also elsewhere on the board
PG13: J3.15; also elsewhere on the board
PG14: J3.14; also elsewhere on the board
PG15: J3.13; also elsewhere on the board
VDD_3.3: J3.27, J3.28, R41.1, R42.1, R43.1; also elsewhere on the board
VSS: J3.29, J3.30; also elsewhere on the board

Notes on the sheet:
SPI0-MOSI
I2C 3 SCL
UART 1 TX
SPI0-SS
PWM1 CH 0
SPI0-SS1
PEN_IRQ_PIN
SPI0-CLK
PWM1 CH 1
UART 1 RX
SPI0-MISO
I2C 3 SDA
LCD-DC

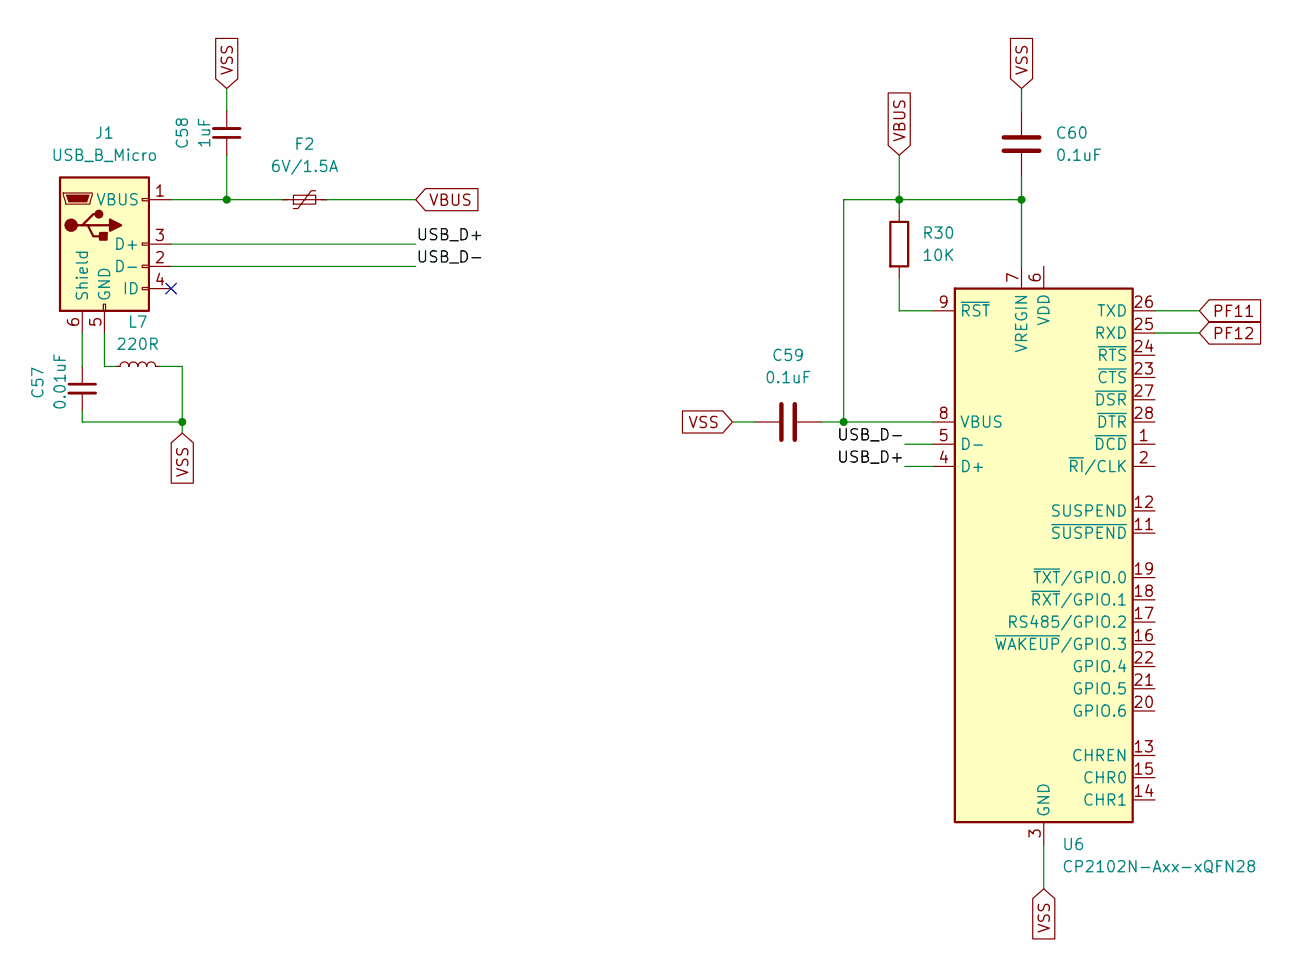
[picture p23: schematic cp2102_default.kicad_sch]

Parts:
C57: 0.01uF; C_0402_1005Metric
C58: 1uF; C_0402_1005Metric
C59, C60: 0.1uF; C_0402_1005Metric
F2: 6V/1.5A; Fuse_0805_2012Metric
J1: USB_B_Micro; USB_Micro-B_Amphenol_10118194_Horizontal
L7: 220R; L_0603_1608Metric
R30: 10K; R_0402_1005Metric
U6: CP2102N-Axx-xQFN28; QFN-28-1EP_5x5mm_P0.5mm_EP3.35x3.35mm

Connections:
/CP2102/USB_D+: J1.3 (D+), U6.4 (D+)
/CP2102/USB_D-: J1.2 (D-), U6.5 (D-)
unnamed: C57.1, J1.6 (Shield)
unnamed: C58.1, F2.1, J1.1 (VBUS)
unnamed: J1.5 (GND), L7.1
unnamed: R30.2, U6.9 (~RST)
PF11: U6.26 (TXD); also elsewhere on the board
PF12: U6.25 (RXD); also elsewhere on the board
VBUS: C59.2, C60.1, F2.2, R30.1, U6.7 (VREGIN), U6.8 (VBUS); also elsewhere on the board
VSS: C57.2, C58.2, C59.1, C60.2, L7.2, U6.3 (GND), U6.29 (GND); also elsewhere on the board

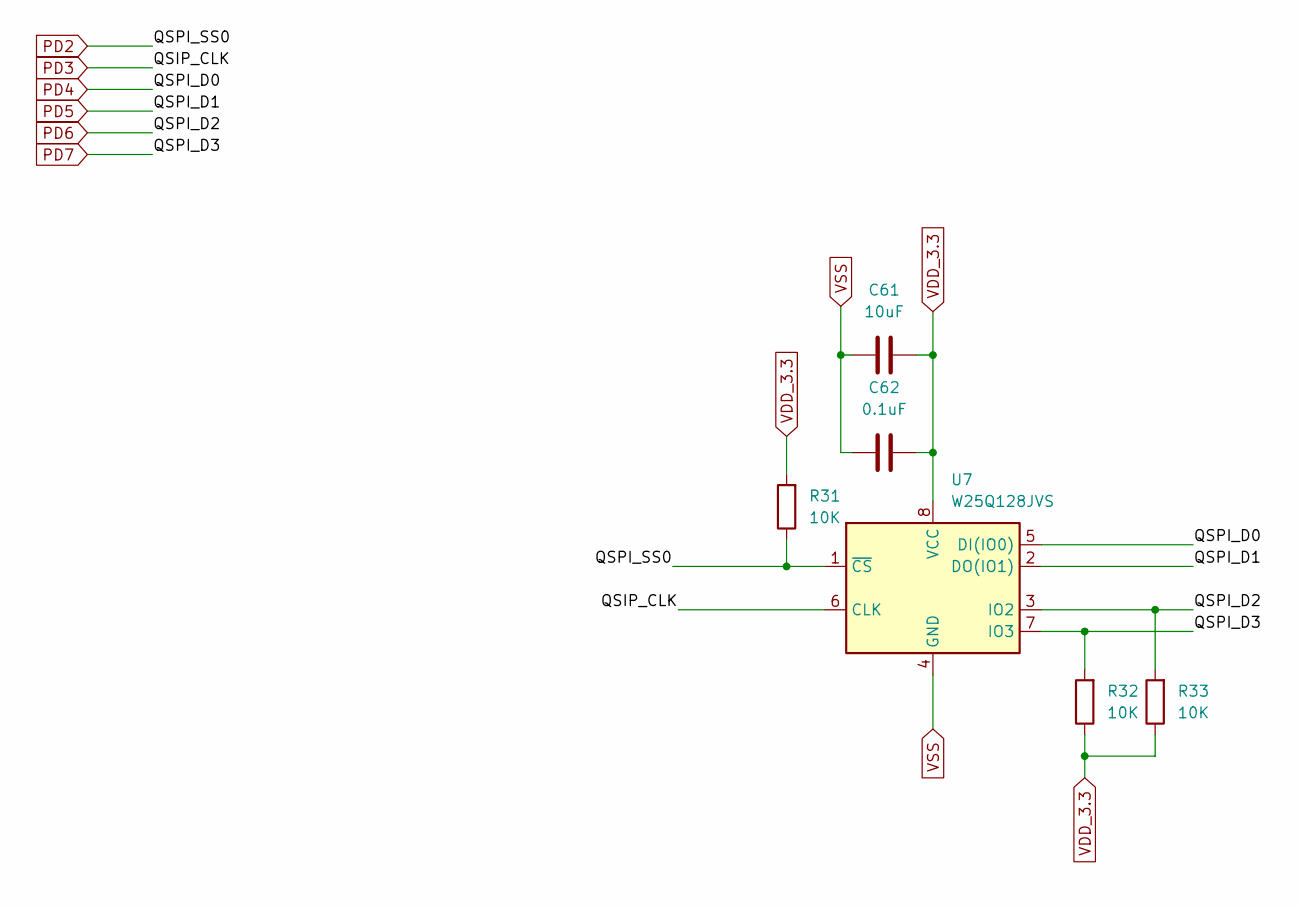
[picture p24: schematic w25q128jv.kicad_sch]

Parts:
C61: 10uF; C_0402_1005Metric
C62: 0.1uF; C_0402_1005Metric
R31, R32, R33: 10K; R_0402_1005Metric
U7: W25Q128JVS; SOIC-8_5.23x5.23mm_P1.27mm

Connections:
PD2: R31.1, U7.1 (~CS); also elsewhere on the board
PD3: U7.6 (CLK); also elsewhere on the board
PD4: U7.5 (DI(IO0)); also elsewhere on the board
PD5: U7.2 (DO(IO1)); also elsewhere on the board
PD6: R33.2, U7.3 (IO2); also elsewhere on the board
PD7: R32.2, U7.7 (IO3); also elsewhere on the board
VDD_3.3: C61.2, C62.2, R31.2, R32.1, R33.1, U7.8 (VCC); also elsewhere on the board
VSS: C61.1, C62.1, U7.4 (GND); also elsewhere on the board

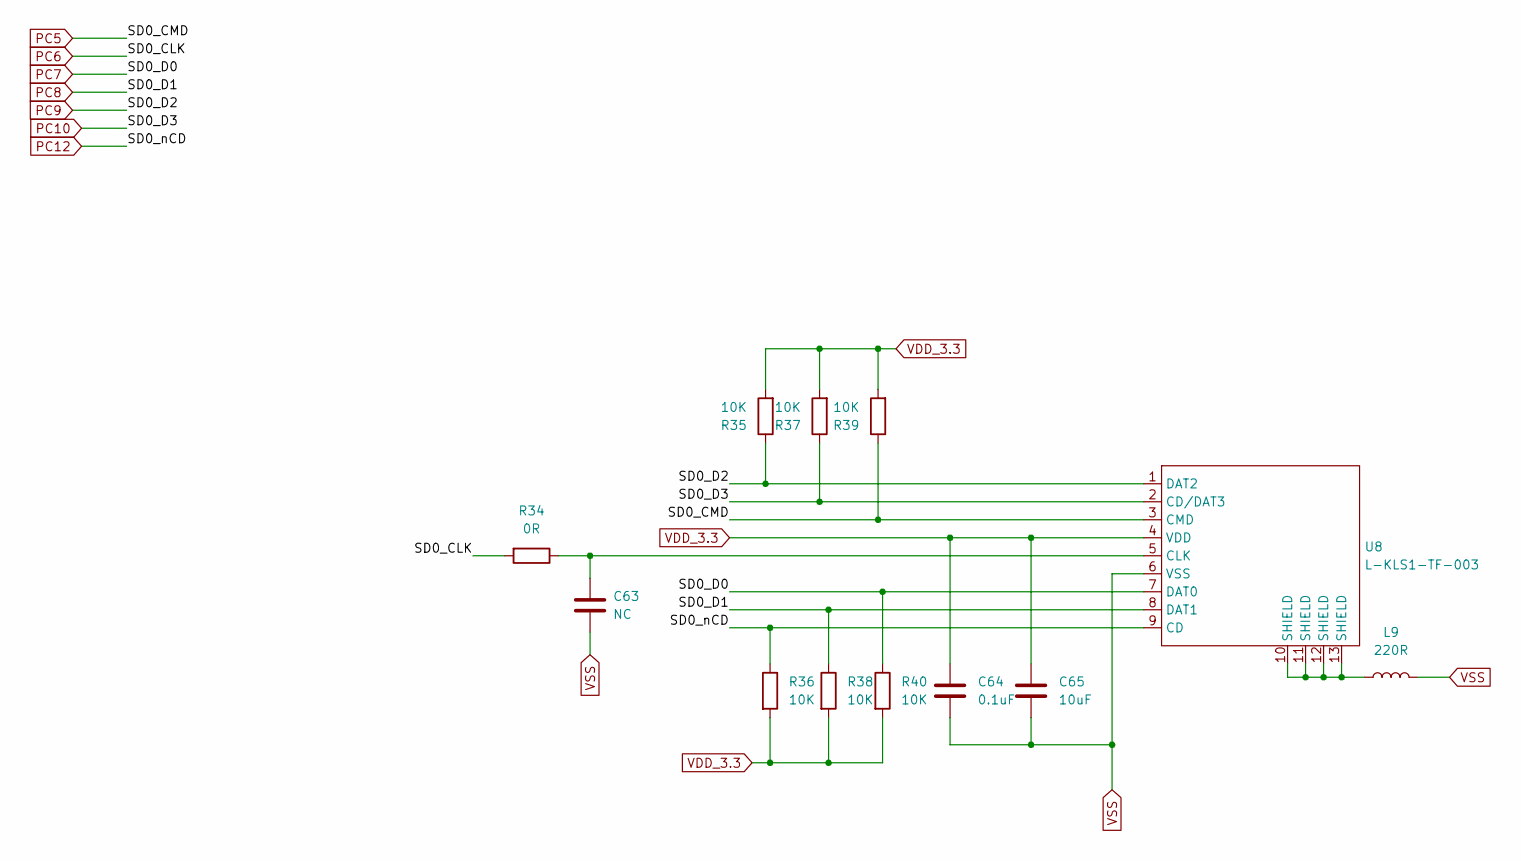
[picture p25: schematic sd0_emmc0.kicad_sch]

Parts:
C63: NC; C_0402_1005Metric
C64: 0.1uF; C_0402_1005Metric
C65: 10uF; C_0402_1005Metric
L9: 220R; L_0603_1608Metric
R34: 0R; R_0402_1005Metric
R35, R36, R37, R38, R39, R40: 10K; R_0402_1005Metric
U8: L-KLS1-TF-003; L-KLS1-TF-003-H1.85-R

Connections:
unnamed: C63.1, R34.1, U8.5 (CLK)
unnamed: L9.1, U8.10 (SHIELD), U8.11 (SHIELD), U8.12 (SHIELD), U8.13 (SHIELD)
PC5: R39.1, U8.3 (CMD); also elsewhere on the board
PC6: R34.2; also elsewhere on the board
PC7: R40.1, U8.7 (DAT0); also elsewhere on the board
PC8: R38.1, U8.8 (DAT1); also elsewhere on the board
PC9: R35.1, U8.1 (DAT2); also elsewhere on the board
PC10: R37.1, U8.2 (CD/DAT3); also elsewhere on the board
PC12: R36.1, U8.9 (CD); also elsewhere on the board
VDD_3.3: C64.1, C65.1, R35.2, R36.2, R37.2, R38.2, R39.2, R40.2, U8.4 (VDD); also elsewhere on the board
VSS: C63.2, C64.2, C65.2, L9.2, U8.6 (VSS); also elsewhere on the board

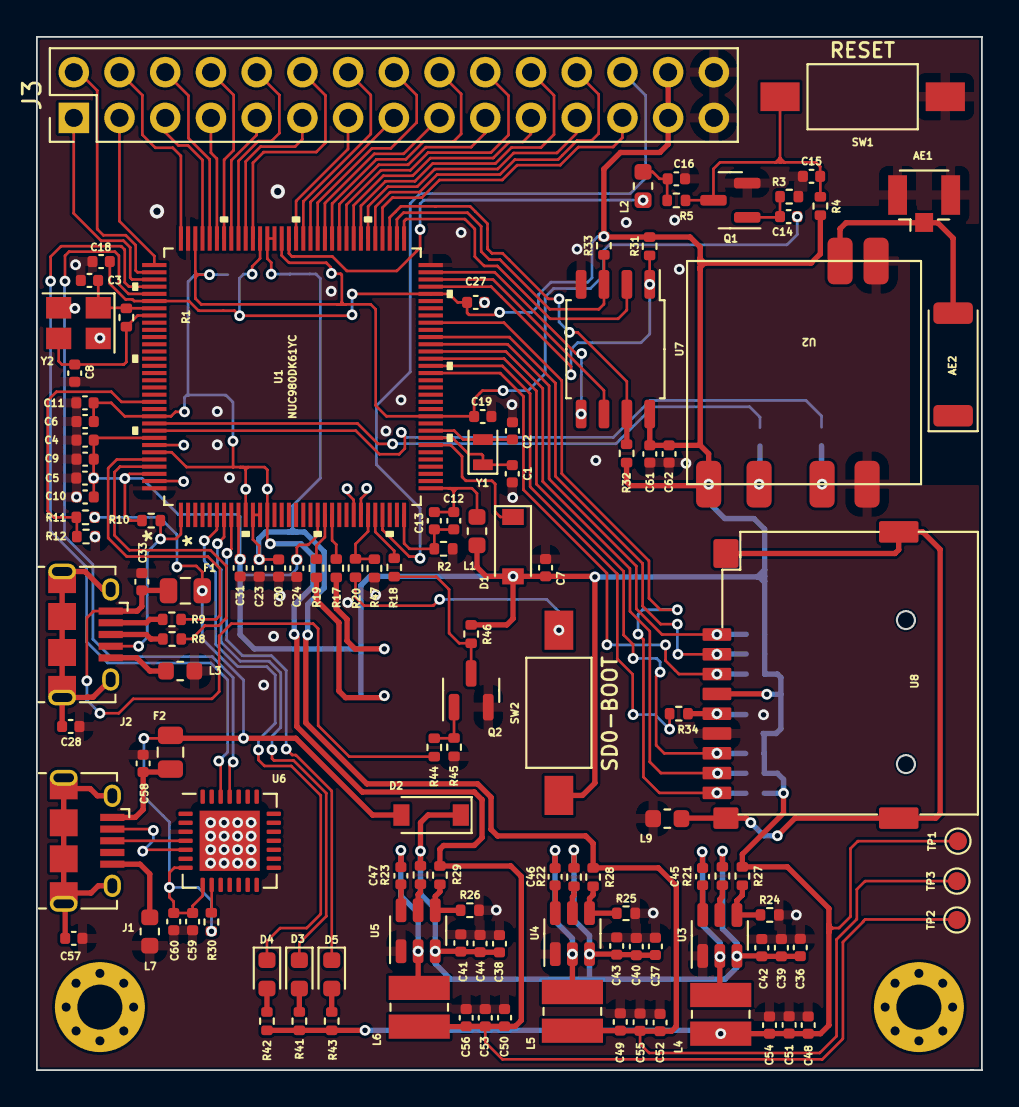
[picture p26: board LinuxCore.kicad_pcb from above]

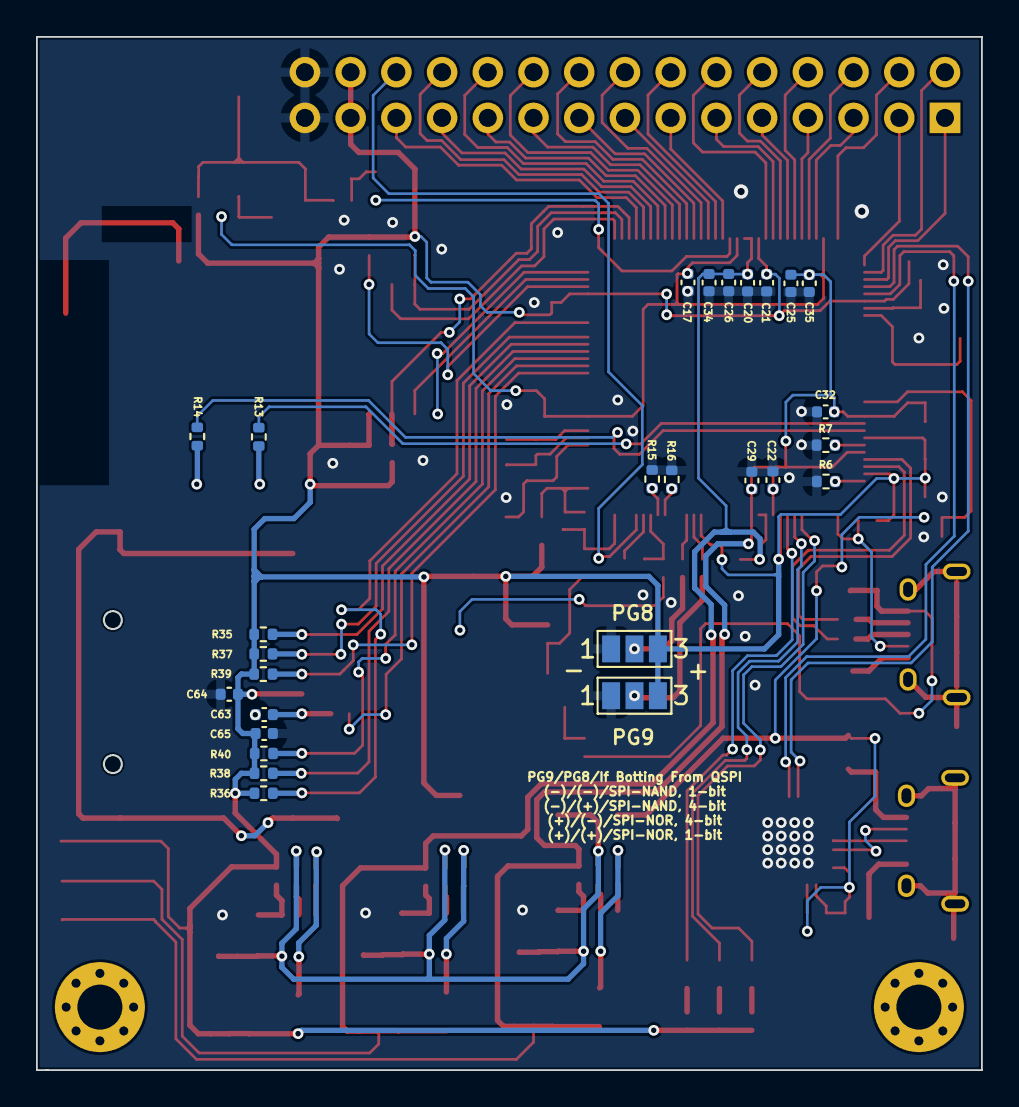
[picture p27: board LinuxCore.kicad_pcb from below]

Board: 2 copper layers, 52.5 x 57.4 mm, 151 parts (27 on the bottom side), 111 nets.

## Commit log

2022-09-05 Update Board
    [LinuxCore.kicad_pcb]
2024-09-30 update 3d model
    [LinuxCore-v2.kicad_pcb, LinuxCore-v2.kicad_sch, nau8822.kicad_sch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]

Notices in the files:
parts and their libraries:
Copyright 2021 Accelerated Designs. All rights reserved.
